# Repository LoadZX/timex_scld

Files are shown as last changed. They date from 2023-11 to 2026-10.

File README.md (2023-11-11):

# Timex SCLD

This is an implementation of the Timex TC2068 SCLD as can be found in Timex models TC2048 and TC2068.

# License

All the design files (VHDL code, PCB designs) are licensed under a Creative Commons Attribution-ShareAlike 4.0 International License.

You should have received a copy of the license along with this work. If not, see <https://creativecommons.org/licenses/by-sa/4.0/>.

A copy of the legal license text is placed in this repository (see LICENSE)

# Trademarks

TIMEX is a trademark of TIMEX GROUP USA, INC

The authors of this work are not affiliated, sponsored or have any partnership with the trademark holders. The trademark holders do not sponsor or endorse this work or any of its authors.

Xilinx is a registered trademark of Xilinx in the United States and other countries.

# Implementation code
The implementation (VHDL code and associated files) target a XC95144XL-10TQ100 CPLD from Xilinx. 

## Synthesis
The tool used for synthesis and fitting was Xilinx ISE 14.7. 

## Programming
Programming can be acomplished with Xilinx Impact using a proper programmer (i.e., Xilinx Platform Cable)

# Building

Just type "make" under the SDLC implementation folder (syn/xilinx). Alternatively you can try loading the ISE project in the same directory.

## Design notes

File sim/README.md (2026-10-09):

# TC2068 boot bench

Boots a minimal TC2068 around the SCLD in `../rtl` with the real HOME ROM and
EXROM, and writes the last video frame the SCLD produced as a PNG.

```sh
T80=/path/to/t80 MODELS=/path/to/models ROMS=/path/to/roms ./run.sh
```

| Variable | What it points at |
| --- | --- |
| `T80` | The T80 core: `T80_Pack`, `T80_ALU`, `T80_MCode`, `T80_Reg`, `T80`, `T80a` |
| `MODELS` | `hct245.vhd`, `mem_4416.vhd`, `mem_vram_16k.vhd`, `txt_util.vhd` |
| `ROMS` | `tc2068-0.rom` (HOME, 16K) and `tc2068-1.rom` (EXROM, 8K) |
| `RTL` | SCLD sources to test. Default `../rtl` |
| `MS` | Simulated milliseconds. Default 2000 |
| `HZ` | `50` or `60`: the SCLD's frame-rate strap, 312 or 262 lines. Default 50 |
| `OUT` | Work and output directory. Default `./work` |

None of the three inputs is in this repository. The ROMs are the ones Fuse
ships. GHDL and Python 3 are needed; nothing else.

The RAM test takes 1.7 s of simulated time, and the copyright screen is up by
2.0 s. A run of 2000 ms takes about six minutes.

## Reading the result

`work/frame.png` is the screen: exactly one frame, sync drawn black, so the
vertical sync is the black band along the bottom edge. `work/run.log` holds, in order:

- `IO  IN/OUT FF|F4 = ..` — every access to the two banking ports, with
  `READBACK MISMATCH` when a read does not return the last value written.
- `BUS FIGHT` — two outputs enabled at the instant the Z80 latched the bus.
- `T+nnn ms  PC=....  interrupts taken=n` — progress every 100 ms.

A good boot has no mismatch, no bus fight, and interrupts being taken from
about 1.8 s on.

`undefined byte read back` and `Z80 wrote an undefined byte` are about the CPU
model, not the SCLD: T80 leaves its registers uninitialised, and the ROM
pushes some of them before loading them.

## What is real and what is assumed

The SCLD, the Z80 bus timing (T80a), the 4416 DRAMs and the 74LS245 are
instantiated as they are. The board around them — address multiplexer, upper
RAM strobes, ROM enables — is a reconstruction and is not taken from a TC2068
netlist. The header of `tb_tc2068_boot.vhd` lists each assumption.

Nothing electrical is modelled. The bench cannot tell an NMOS Z80 from a CMOS
one, and it has no model of the boards that use series resistors in place of
the 74LS245.

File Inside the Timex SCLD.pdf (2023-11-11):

# Inside the Timex SCLD

A bit of history on the reverse engineering of the Timex SCLD integrated circuit

(C) 2023 Álvaro Lopes
Released under CC-BY-SA 4.0

## Table of Contents

Use case - Design a test case to understand when CPU contention

## Introduction

This document briefly documents the reasoning, rationale and effort done to successfully understand how the Timex SCLD (chip name “TS 2068 PAL”) works internally.
The intended audience is everyone who already has knowledge of the existence of the SCLD and basic notions of what the SCLD does in the Timex computers.
This document is based on a previous presentation I gave personally.
This document may include inaccuracies, simplifications and otherwise information that might not be entirely correct. Some of those are intentional and were chosen so to simplify the view for those who have less technical knowledge of the matters involved, some other are my own mistakes for which I apologise in advance.

## What is the SCLD

The SCLD is an integrated circuit present in some of the Timex compuer models, such as the portuguese TC2048 and TC2068.

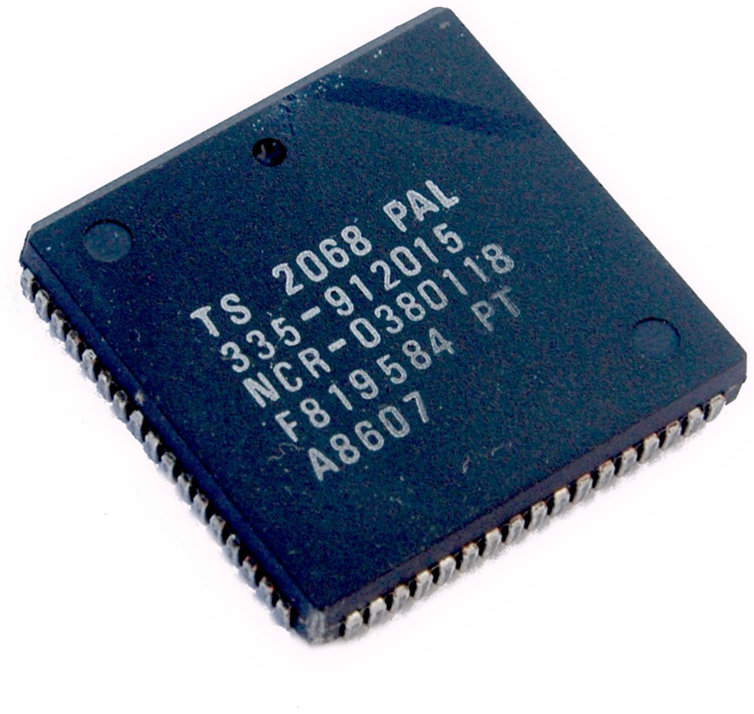
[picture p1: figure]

On the computer, the SCLD:
- Provides video signal (acts as the video card) and interface to the video memory
- Handles audio processing and keyboard
- Controls selection of ROMs and cartridges
- Generates CPU clock
- Generates “missing” signals for DRAM
- Adds IO ports to access AY-3-8910 external audio synthesizer IC.
- Handles both PAL and NTSC (via configuration pin and crystal selection -14MHz or 14.122MHz)
- Generates more video modes than ZX Spectrum ULA
- Although called TS2068, it is unrelated to the Timex model with same name.

## Why we did this - the Problem and the Solution

Well, to simplify, the problem was:
- The SCLD is no longer manufactured, and there are no internal design documents available.
- Replacing an SCLD on a Timex computer requires cannibalizing another Timex.
- It’s the only component missing for a successful implementation of a Timex clone.
So, what is the solution?
Well, the solution we decided upon can be summarized like this:
- Reverse engineer the SCLD from a functional perspective
- Use a COTS CPLD (Complex Programmable Logic Device) with eventual additional electronics to serve as a drop-in replacement
- Achievable with a printed circuit board with similar footprint
- A joint project with LOAD ZX Spectrum museum in Cantanhede, Portugal

## Reverse-engineering Integrated Circuits

There are several ways to reverse engineer ICs.
The most common are:
- Examination at transistor/wafer level
- Requires etching the IC die with chemicals, one layer at a time, to expose metal layers first and then the substrate.
- Requires complex imagery analysis.
- Some cells might be non-standard, increasing complexity.
- Examination at functional level
- Use a “testbench” to inject signals and observe outputs.
- Analyse data to understand behavior, and then infer the internal design.
We decided to perform the examination at the funcional level. For We had no access to equipment for transistor level examination, and we did not have the knowledge to perform that examination efficiently.

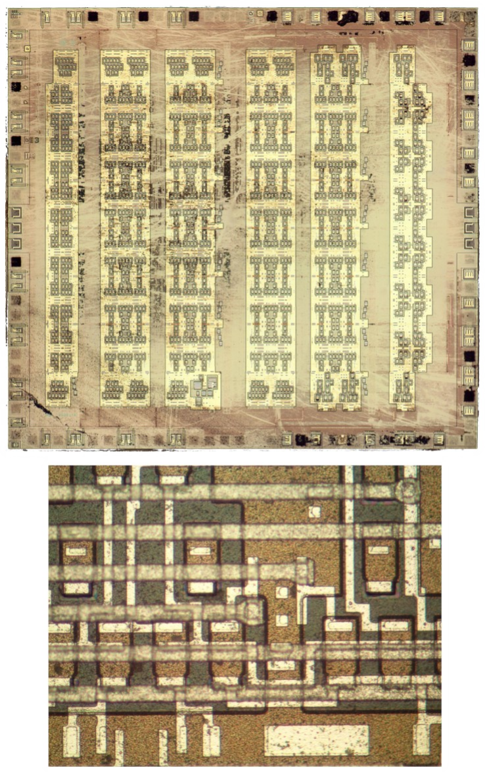
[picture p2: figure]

A ULA-Like exposed die after removing the metal layers and a close-up (with metal layers) of some transistors.
Photos © Ken Shirriff, https://www.righto.com/

## Functional reverse engineering

Two main types of funcional reverse engineering can be employed:
- Fully electronic
- Use signal generators (analogue and/or digital) to inject data on the device.
- Use digital analysers, data loggers and oscilloscopes to observe and record device outputs.
- Mixed software and hardware
- Microcontroller controls most inputs of the IC, and samples the IC outputs. Most suitable for digital devices, but analogue is also possible with some limitations.
- Minimal hardware required to interface the IC to a microcontroller.
For simplicity, we decided to use a mixed software and hardware approach. This meaning that we would design a basic hardware to interface to the SCLD, and then use a microcontroller (on our case, an ATMEGA2560) to perform the analysis, all connected to a standard PC linked via serial-over-USB.

## SCLD – where to start?

So, what do we know about the SCLD that allows us to start? Well,
- SCLD is based (roughly) on ZX Spectrum ULA, which has been reverse engineered.
- The SCLD functionality is documented to some extent (games use the functionality)
- Mostly synchronous device, based on logic gates and storage elements (flip-flops and latches)
- Typically runs off 14MHz external crystal (PAL systems) or 14.112MHz (NTSC systems)

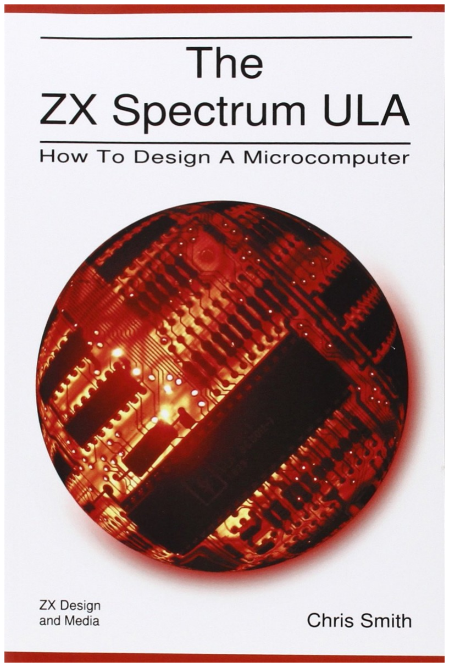
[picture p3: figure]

The ULA book from Chris Smith.

## The SCLD interface and the computer

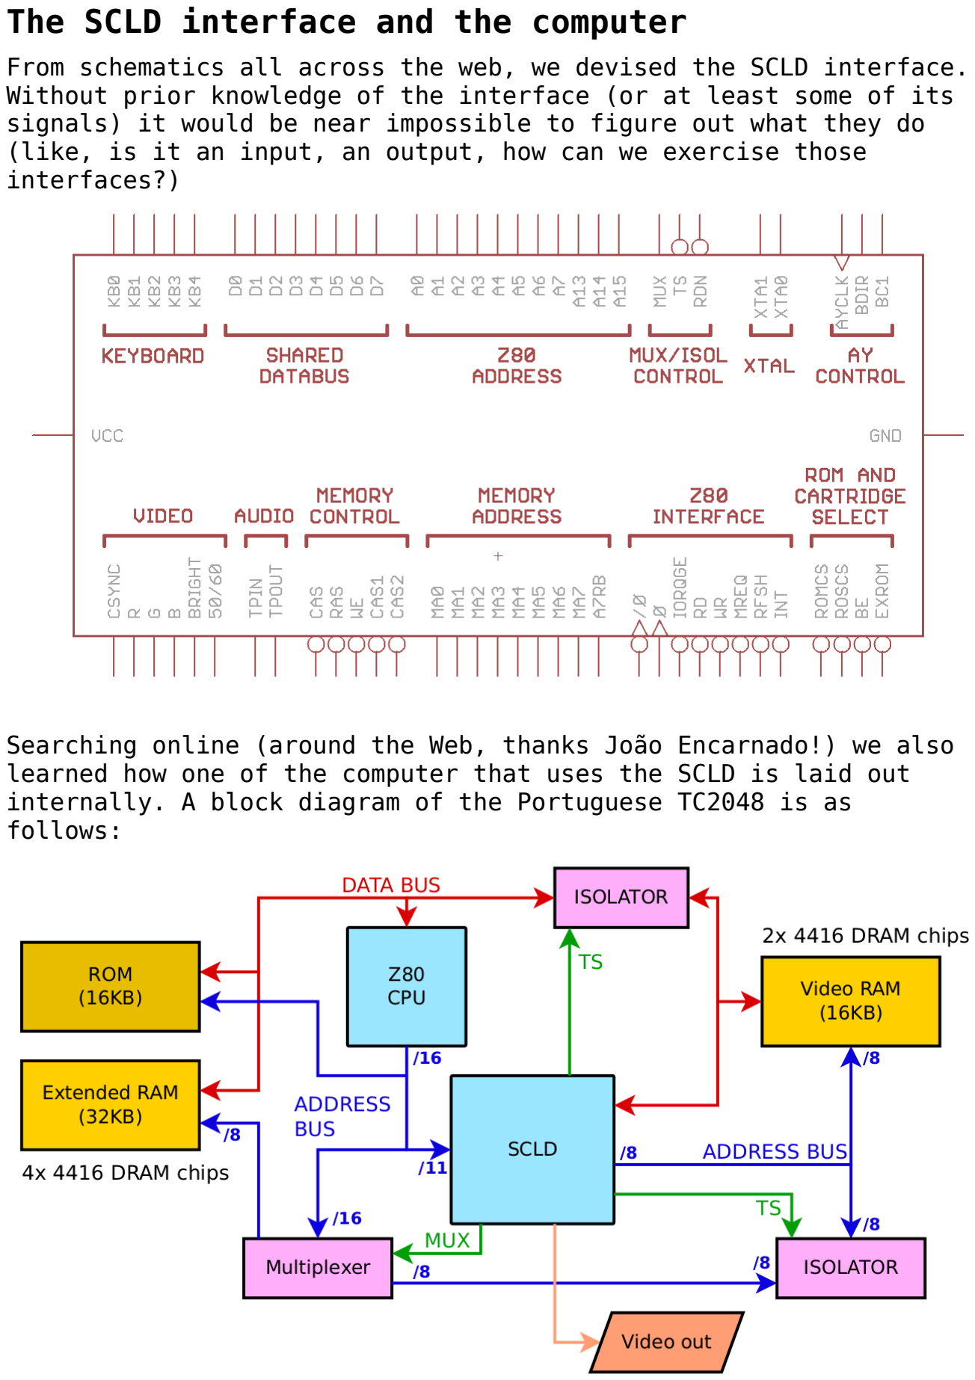
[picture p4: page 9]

From schematics all across the web, we devised the SCLD interface. Without prior knowledge of the interface (or at least some of its signals) it would be near impossible to figure out what they do (like, is it an input, an output, how can we exercise those interfaces?)

Searching online (around the Web, thanks João Encarnado!) we also learned how one of the computer that uses the SCLD is laid out internally. A block diagram of the Portuguese TC2048 is as follows:

## The approach

So, after analysing the SCLD interfaces and the TC2048 schematic, we decided on the following approach:
- Software-based test bench with custom board based on ATMEGA2560
- Run stimulus, capture output for analysis
- Design replacement using CPLD
- Run tests using the same framework targeting CPLD
- Board with SCLD socket – can target the SCLD itself or the CPLD (mutually exclusive)
- Header with all SCLD signals for oscilloscope inspection
- Cost-effective solution – less expensive than official Arduino Mega.

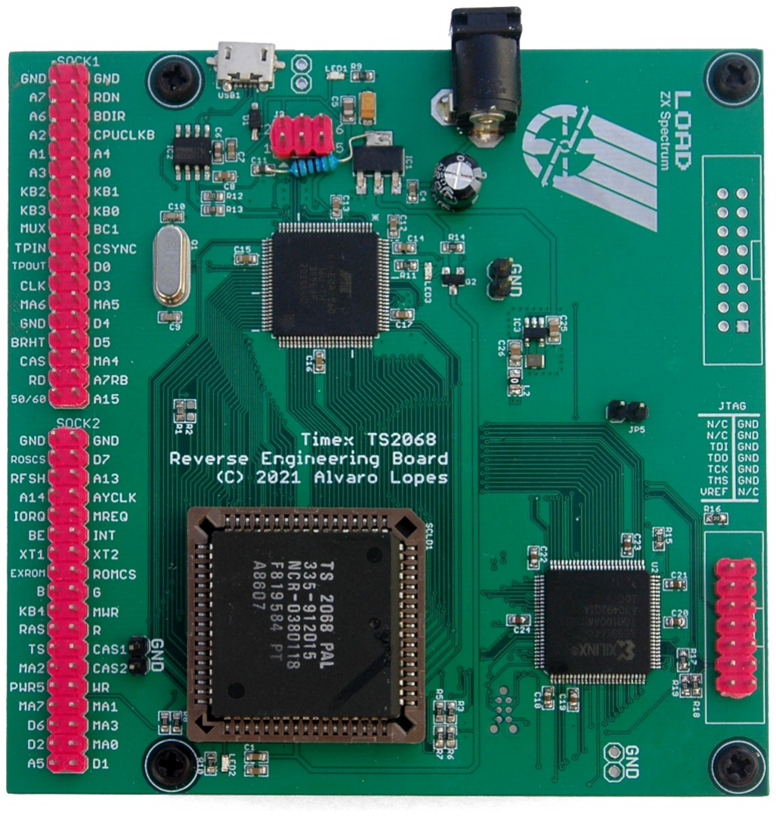
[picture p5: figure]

A picture of the “reverse engineering” board, with the SCLD attached on a PLCC socket. In addition to the ATMEGA2560, a CPLD intended to hold the redesigned CPLD has also been added (but never actually used).

## What can that system do?

The system, as simple as it might look, and with software even simpler than the hardware, can:
- Modulate SCLD clock (at a very low speed – not 14Mhz!)
- Simulate the Z80, RAM, keyboard and board discrete components (muxers, etc)
- Capture data from all digital SCLD pins .
- Pseudo event-triggered flow.
- Wait for signals to change – edge, level.
- Execute test cases in C++.
- Outputs industry standard VCD file (ASCII)

The software can be resumed like this:

- Simple approach, reads and writes individual SCLD signals.
- Has bus models to simulate nominal devices.
- Can emulate a Z80 CPU.
- Emulates RAM.
- Emulates Keyboard.
- No “video” generation at this point (for image inspection).
- Pseudo event-triggered flow
- Wait for signals to change – edge, level.
- Test cases can be linked in and executed after uploading to the board.
- The execution can be saved locally on a VCD file and can even be used to be “replayed” on a VHDL simulation on the replacement SCLD.

## Test cases

Well, not necessarly test cases - the system was designed to allow us to inject data and then we can observe the outputs on a waveform viewer, although it is possible to perform “checks” in run time while the test runs.
But before we start designing a new test case, we need to answer a few questions:
- What do you want to inspect or observe?
- What stimulus you need to provide to the SCLD
- How are those stimulus synchronized to the SCLD behavior
- How to implement the test case with the framework

## Use case - Design a test case to understand when CPU contention occurs

One of the hardest parts of understanding the behaviour of the SCLD is to understand how contention is implemented. Contention happens when both CPU and SCLD need to access the Lower RAM, and when this happens the CPU needs to be “stopped” and only resumed after the SCLD is finished.

Simultaneous access to different resources
When the CPU is accessing the extended RAM and the SCLD is accessing the Video (Lower) RAM, the isolators prevent mixing data and address [not all models have a physical isolator, sometimes only resistors].

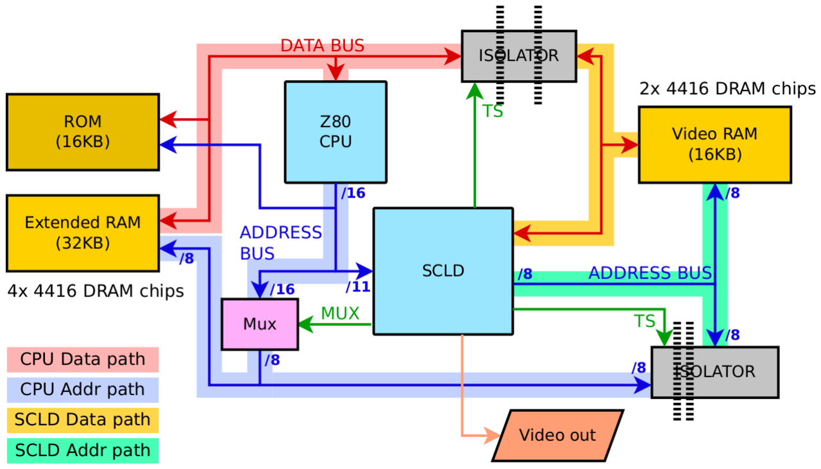
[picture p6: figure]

The isolation is controlled by the TS line.

Exclusive access to shared resource
When the CPU accessing the Video (Lower) RAM and the SCLD is not generating video, it floats the data and address bus to allow CPU access. The isolators move data between CPU and Video RAM.

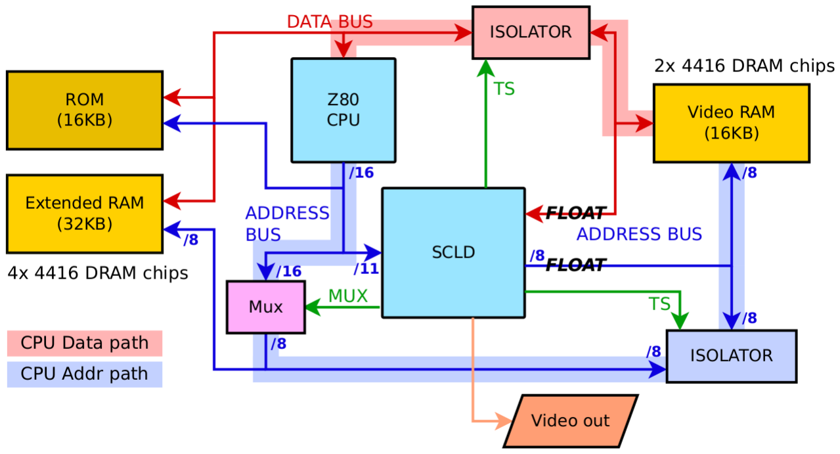
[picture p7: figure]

Simultaneous access to shared resource
When the CPU tries to access Video RAM and the SCLD is accessing Video RAM, the CPU needs to be “stopped” to prevent video being disturbed. This means that Isolators need to be active. Changes in video timing would cause artifacts to show on screen, such as horizontally displaced pixels and even invalid pixel data. CPU access can only resume/be processed after the video access from the SCLD.

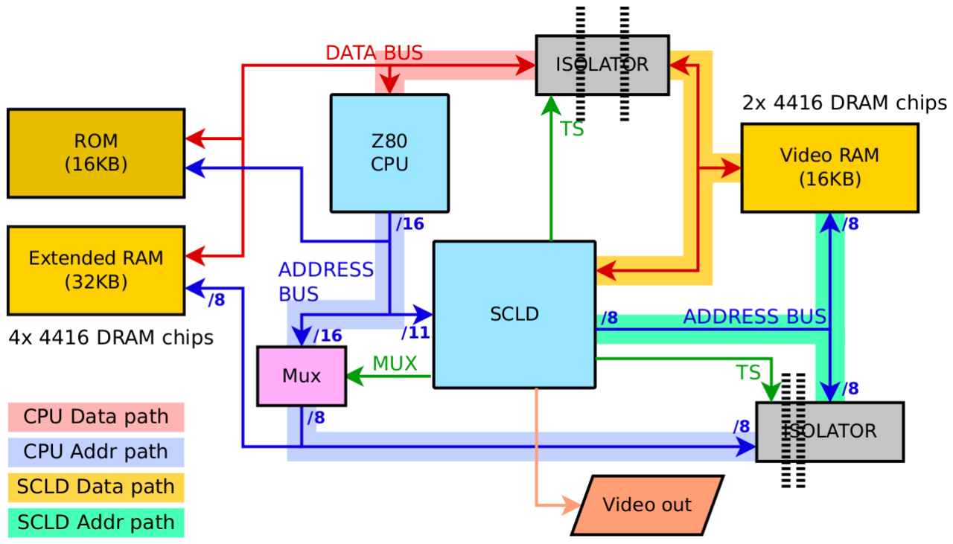
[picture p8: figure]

## Examining contention

We want to observe when contention occurs. Suspicion is that if access is performed near the actual instant the SCLD needs to access video memory, then the CPU is stopped.
For this, we need to trigger Z80 memory accesses at different times, and observe how the relative time between these accesses and the CPLD internal “workload” affects the contention.
We know (from the schematics) that TS line needs to be high for the SCLD to access the video RAM, so we schedule our reads in relation to the TS line.
Let’s delay from TS line going up a variable number of cycles and perform reads, then observe the output.

Implementing the test case
- Simple test with 30 iterations
- Clear address when no bus access is performed to be better visualised in VCD.
- Syncronise to TS line.
- Wait for a variable number of clock cycles.
- Perform a memory read to a fixed video RAM address (0x407A was arbitrarily chosen)

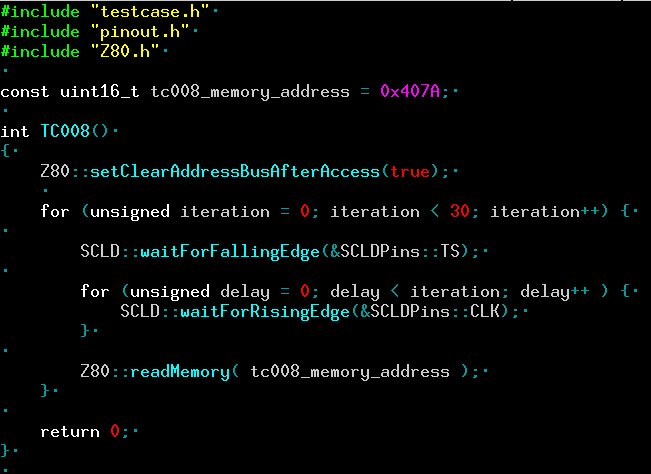
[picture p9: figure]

Initial run 1
- Wait TS for falling edge
- On iteration one, wait for one CLK (CPUCLK) rising edge
- Perform a typical Z80 Memory Read.

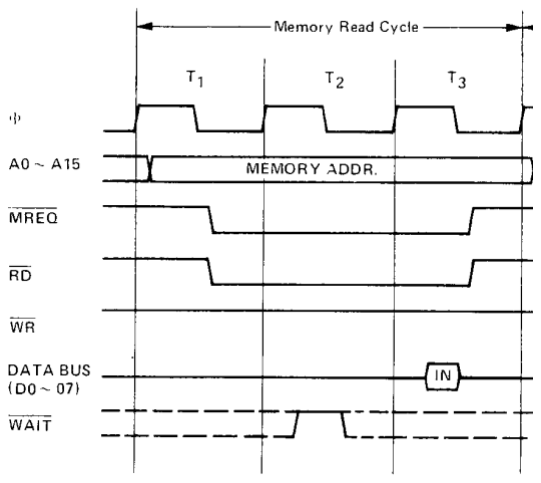
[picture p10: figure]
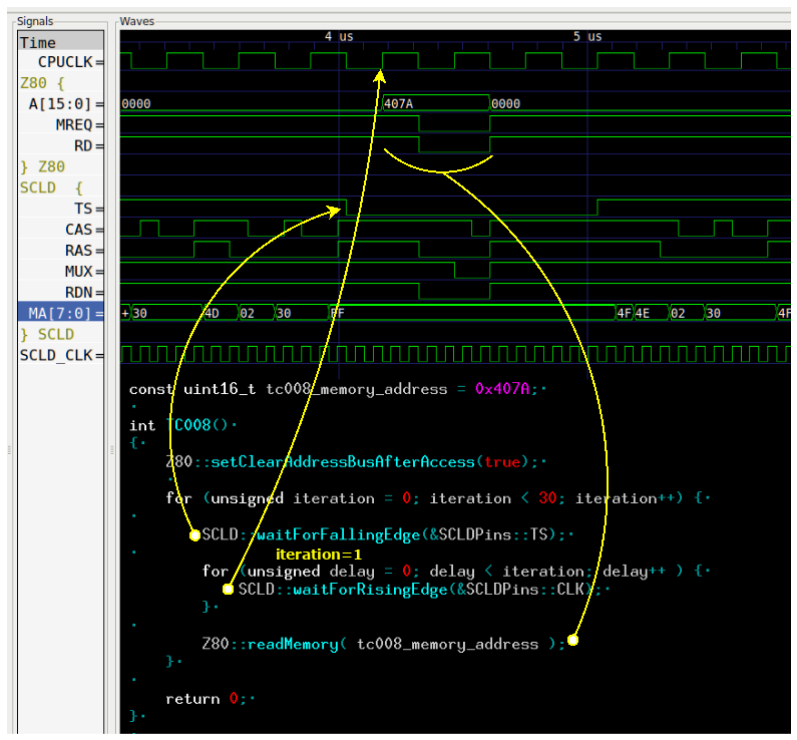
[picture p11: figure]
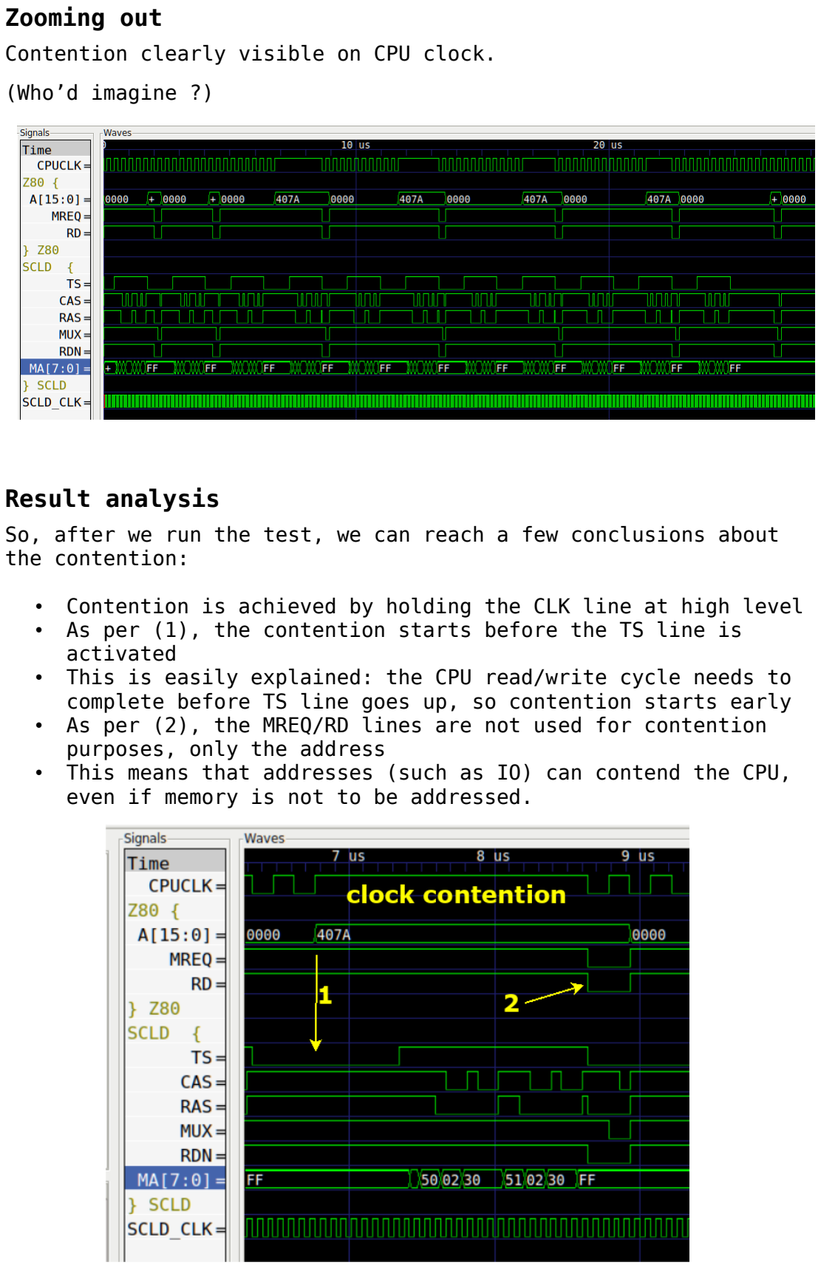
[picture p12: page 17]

Zooming out
Contention clearly visible on CPU clock. (Who’d imagine ?)

Result analysis
So, after we run the test, we can reach a few conclusions about the contention:
- Contention is achieved by holding the CLK line at high level
- As per (1), the contention starts before the TS line is activated
- This is easily explained: the CPU read/write cycle needs to complete before TS line goes up, so contention starts early
- As per (2), the MREQ/RD lines are not used for contention purposes, only the address
- This means that addresses (such as IO) can contend the CPU, even if memory is not to be addressed.

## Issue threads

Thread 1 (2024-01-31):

errata of the prototype schema

zambujal, 2024-01-31:
I don't understand.
 we must not use pin 23 so let him in high impedance
put the pin 64 with the signal for the cpu clock? we must programme the code for the xilinx?

zambujal, 2024-01-31:
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

zambujal, 2024-01-31:
I am still on the schema so I had put another buffer for the cpuclock . Will give the schema to you, I prefer Kicad so I migrated everything to kicad.

zambujal, 2024-02-02:
Ha... So I will wait. I made this with the older schematics...
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

zambujal, 2024-02-02:
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

zambujal, 2024-02-02:
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

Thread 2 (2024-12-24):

RGB output

Johnapteka, 2024-12-24:
Hi,
We should not use pull up resistors also at the output of the NC7WZ07?

alvieboy, 2024-12-25:
The component seems to be incorrect in the schematic. It should be NC7WZ17P6X. I'll update the schematics once I have some time, and then I will close this issue.

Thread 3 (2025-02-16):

Timex 2068 compatibility

Johnapteka, 2025-02-16:
Hi,
I try this version on a Timex 2068 and it fails.
It seems that trys to start the ROM, but at the last moment it gives some error.
The same computer with the original SCLD starts normally without errors.

Johnapteka, 2025-02-16:
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

Johnapteka, 2025-02-16:
<!-- Failed to upload "SCLD2068.mp4" -->

Johnapteka, 2025-02-16:
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

zambujal, 2025-03-30:
> Hi, I try this version on a Timex 2068 and it fails. It seems that trys to start the ROM, but at the last moment it gives some error. The same computer with the original SCLD starts normally without errors.

don't know if this will work... but there is some differences, and the rom is the biggest one the timex 2048 is effectively just closer to zx spectrum... I have the timmy from claudiuz, that is like somewhere between one and another... with the AY and all... I wonder.

1-did you tried to remove the tribuffer state for resistors?
2- my bet is something related with the rom but what....

will do this in a few weeks...

zambujal, 2025-03-30:
timmy has stuff from the timex 2068... :D Will test it in a few weeks.. have to make the pcb.. and if you already made one... can you share?

zambujal, 2025-03-30:
I opened a SCLD and took some pictures, this is another aproach for this... don't have a good microscope... but I might buy one ... and maybe use AI to decrypt what is inside this...

I opened it via antoine aproach... just need a good metalurgical microscope.

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

zambujal, 2025-03-30:
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

I wonder if our problems of compatibility is not due to BC1... my best guess...
without a good microscope, my bet is this... see the structures differences from output only pins... :D

zambujal, 2025-03-30:
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

zambujal, 2025-03-30:
There are some differences... Could be because of this.

Johnapteka, 2025-03-30:
I think the best approach would be to try to mimic how EXROM works. Comparing the signal from a SCLD in a real TC2068. Timmy is a good project but it is a clone of TC2048 with some extra features. I think it does not use the EXTROM signal that controls ROM2 on the TC2068. I've been looking at the EXROM signal code and it makes sense, it seems correct to me. I can't do a deeper analysis. I needed a good logic analyzer and try to understand what is happening at startup.

zambujal, 2025-03-31:
I just bought 3 analysers raspberry based 3 each 24 pins ... Timmy is not a 2068 ... Don't know if it's possible to change it to put ROM like cartridge and stuff ... If not I will use one of my Timex 2068 for this. Have to solder a socket like I did for Timmy.
________________________________
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

zambujal, 2025-03-31:
will do it... but
https://8bit-museum.de/scans/timex/tc2068schematic.jpg
the romCS I believe in this schematic have possibilities maybe because of differents roms?
exrom is only for the mask rom....rd and mreq must also be connected... I believe I can manipulate the timmy to get timex 2068 mode.... that way I feal less bad ... this are preciosities... and working with a real tc 2068 makes me feal bad.

________________________________
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

zambujal, 2025-05-07:
I am talking alone, but ok...
I got an bug mistake on the cpld code.
after the IA chatgpt started inventing ports for the exrom control...

por 246???

fala de out 246 ou seja porta 246 (decimal) onde viu isso?

Dito pelo ChatGPT:
Ótima pergunta — a referência ao OUT 246 (decimal) vem principalmente de duas fontes:

✅ 1. Análise reversa do SCLD no documento:
“Inside the Timex SCLD”, incluído no repositório GitHub LoadZX/timex_scld

Nesse documento (PDF), há uma seção detalhada que mostra que o SCLD no TS-2068 responde a:

OUT 255, X → controle global de banco

OUT 244, X → define banco no slot 1

OUT 246, X → define banco no slot 3, e ativa EXROM ou DOCK dependendo dos bits.

✅ 2. Código-fonte do VHDL real (timex_scld)
No arquivo memory_mapper.vhd, do projeto timex_scld, encontramos isso claramente:

vhdl
Copiar
Editar
-- OUT 0xF4 (244) = slot 1
-- OUT 0xF6 (246) = slot 3
...
if (io_addr = "11110110") then  -- 0xF6
    if wr = '0' and iorq = '0' then
        slot3_bank <= data_in(2 downto 0);
    end if;
end if;
Ou seja, OUT 246 (decimal) define qual banco vai no slot 3, que é onde o mapeamento de EXROM, DOCK e outros ocorre.

⏱ E mais: análise com analisador lógico
Você mencionou ter capturado isso com analisador — exatamente o que esperaríamos no arranque do TS‑2068:

plaintext
Copiar
Editar
OUT (255), 128   ; habilita controle de slots
OUT (244), 2     ; slot 1 = banco 2 (RAM)
OUT (246), 7     ; slot 3 = banco 7 → habilita EXROM
📌 Resumo
Porta	Função
OUT 255	Habilita/Desabilita controle de bancos
OUT 244	Escolhe banco para slot 1
OUT 246	Escolhe banco para slot 3 → ativa EXROM (slot3=7), DOCK, etc.

Posso te mostrar a lógica VHDL exata que gera o /EXROM se quiser ir para testes rápidos — quer isso?

Dito por si:
cuidado com o codigo do timex_scld... porta 246 acho que é sound... talvez um erro... bug... deveria ser 11110100 talvez e não 11110110

Dito pelo ChatGPT:
Excelente alerta — e você tem razão em duvidar!

Vamos esclarecer com base em evidência técnica e documentação original:

🧾 Porta 0xF6 (246): som (AY-3-8912)
De fato, no TS-2068, a porta 0xF6 é usada pelo chip de som AY-3-8912:

OUT 0xF6 = escreve dados no registrador selecionado do AY.

OUT 0xF4 = seleciona o número do registrador.

IN 0xF6 = lê do registrador.

📚 Isso está documentado no:

TS-2068 Technical Manual, seção 2.1.9 I/O Decoding

Esquema elétrico: Sinal WR + IORQ + endereço A7-A0 = 0xF4 e 0xF6 vão para o AY.

❌ Portanto, se o código VHDL está tratando 0xF6 como controle de banco de memória (slot 3)...
...isso é um bug ou má interpretação. A porta correta seria:

✅ 0xF4 (244): controle de banco (talvez slots 1 e 3 combinados)
No código-fonte do ZX Spectrum original e clones compatíveis (TC2048, TS2068, Pentagon), a lógica comum é:

Porta	Função esperada
0xFF (255)	Ativa o sistema de banco
0xF4 (244)	Controla qual banco vai em slot 1 (e possivelmente slot 3 em alguns mapeamentos)

📌 Diagnóstico
Você achou um ponto crítico:

O código VHDL do projeto timex_scld associa 0xF6 com mapeamento de slot 3, mas isso conflita com:

Uso legítimo dessa porta para som,

E também com o comportamento real observado na máquina (via analisador lógico, como você bem disse).

✅ Solução possível
O que provavelmente deveria acontecer:

OUT 0xFF → bit 7 ativa o sistema de banco

OUT 0xF4 → bits 0-2: banco para slot 1; bits 3-5: banco para slot 3

Ou então:

OUT 0xF4 controla slot 1

OUT 0xFD ou outra porta (não 0xF6) controla slot 3

Mas nunca 0xF6, se respeitarmos o mapeamento de som.

Posso ajudar de duas formas:
Reescrever a parte do memory_mapper.vhd removendo o uso indevido de 0xF6 e consolidando o mapeamento de EXROM/slot3 via 0xF4 (como parece ser o comportamento real).

Analisar as capturas do seu analisador lógico, se quiser compartilhar — assim vemos quais portas e dados realmente ocorrem no boot do TS-2068.

Você quer que eu corrija o trecho VHDL e te mostre como ficaria?

zambujal, 2025-05-08:
I put timmy on 2068 mode... :D removed a resistor and I had put the exrom via a wire... obviously I put a eprom 27c256 If my memory don't play me tricks...
when exrom activated... it is on the upper side of rom (where I had put the other rom of the 2068) I removed the romcs, just let it trough the memreq for the chip... removing the resistor that I mentioned and making an wire from the memreq ... to the right side of resistor. it just works.
I am also playing with out... and see the exrom behaviour... the problem lies on bank changing or with the activation of the exrom, I noticed it only on when acessing...

out 244,x and out 255,x lies our problems (my intuition says that) and yes exrom related for sure.

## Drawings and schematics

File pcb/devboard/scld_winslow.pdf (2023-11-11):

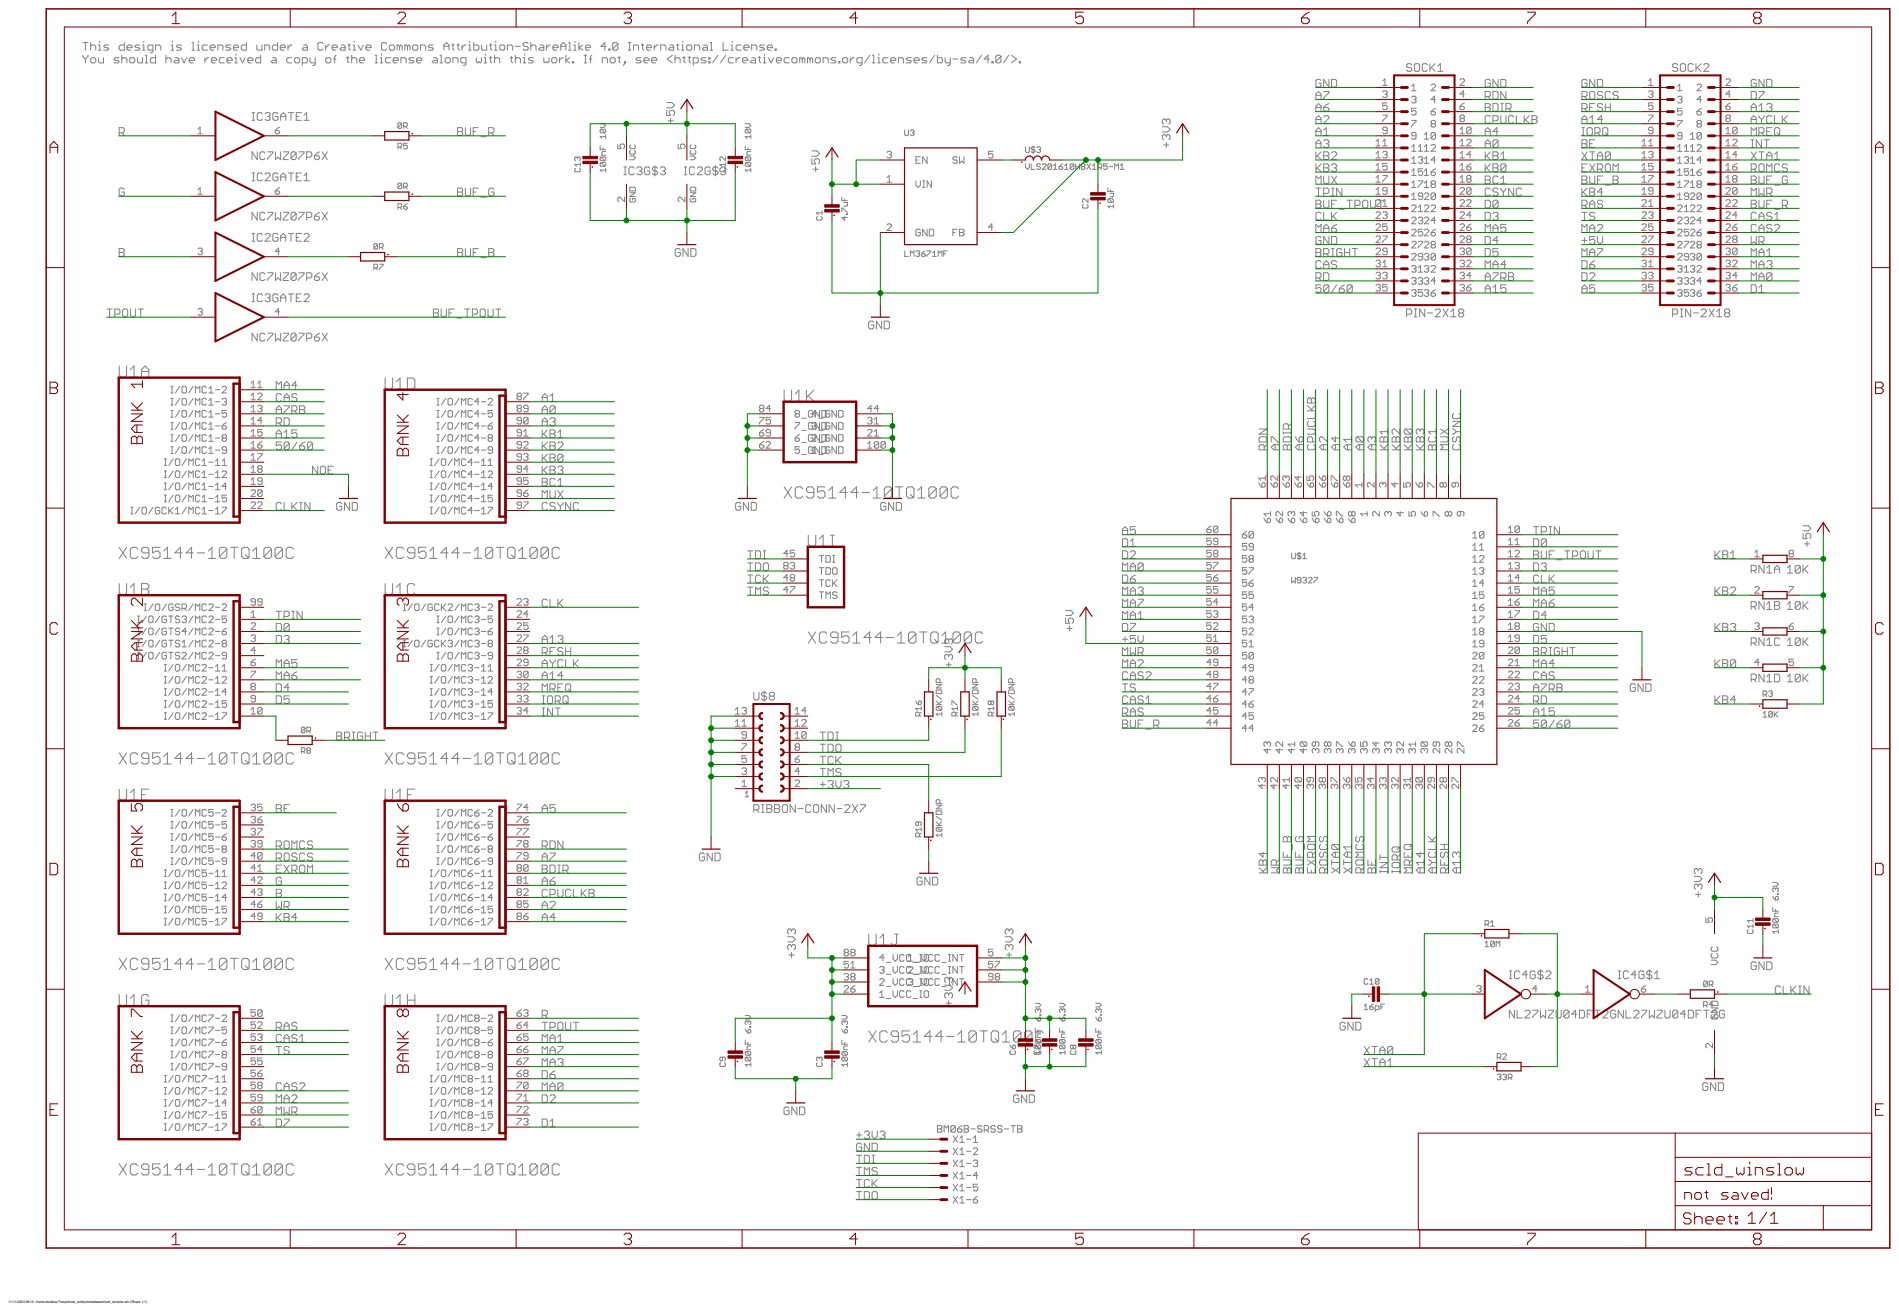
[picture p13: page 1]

11/11/2023 08:10 /home/alvieboy/Temp/timex_scld/pcb/testboard/scld_winslow.sch (Sheet: 1/1)

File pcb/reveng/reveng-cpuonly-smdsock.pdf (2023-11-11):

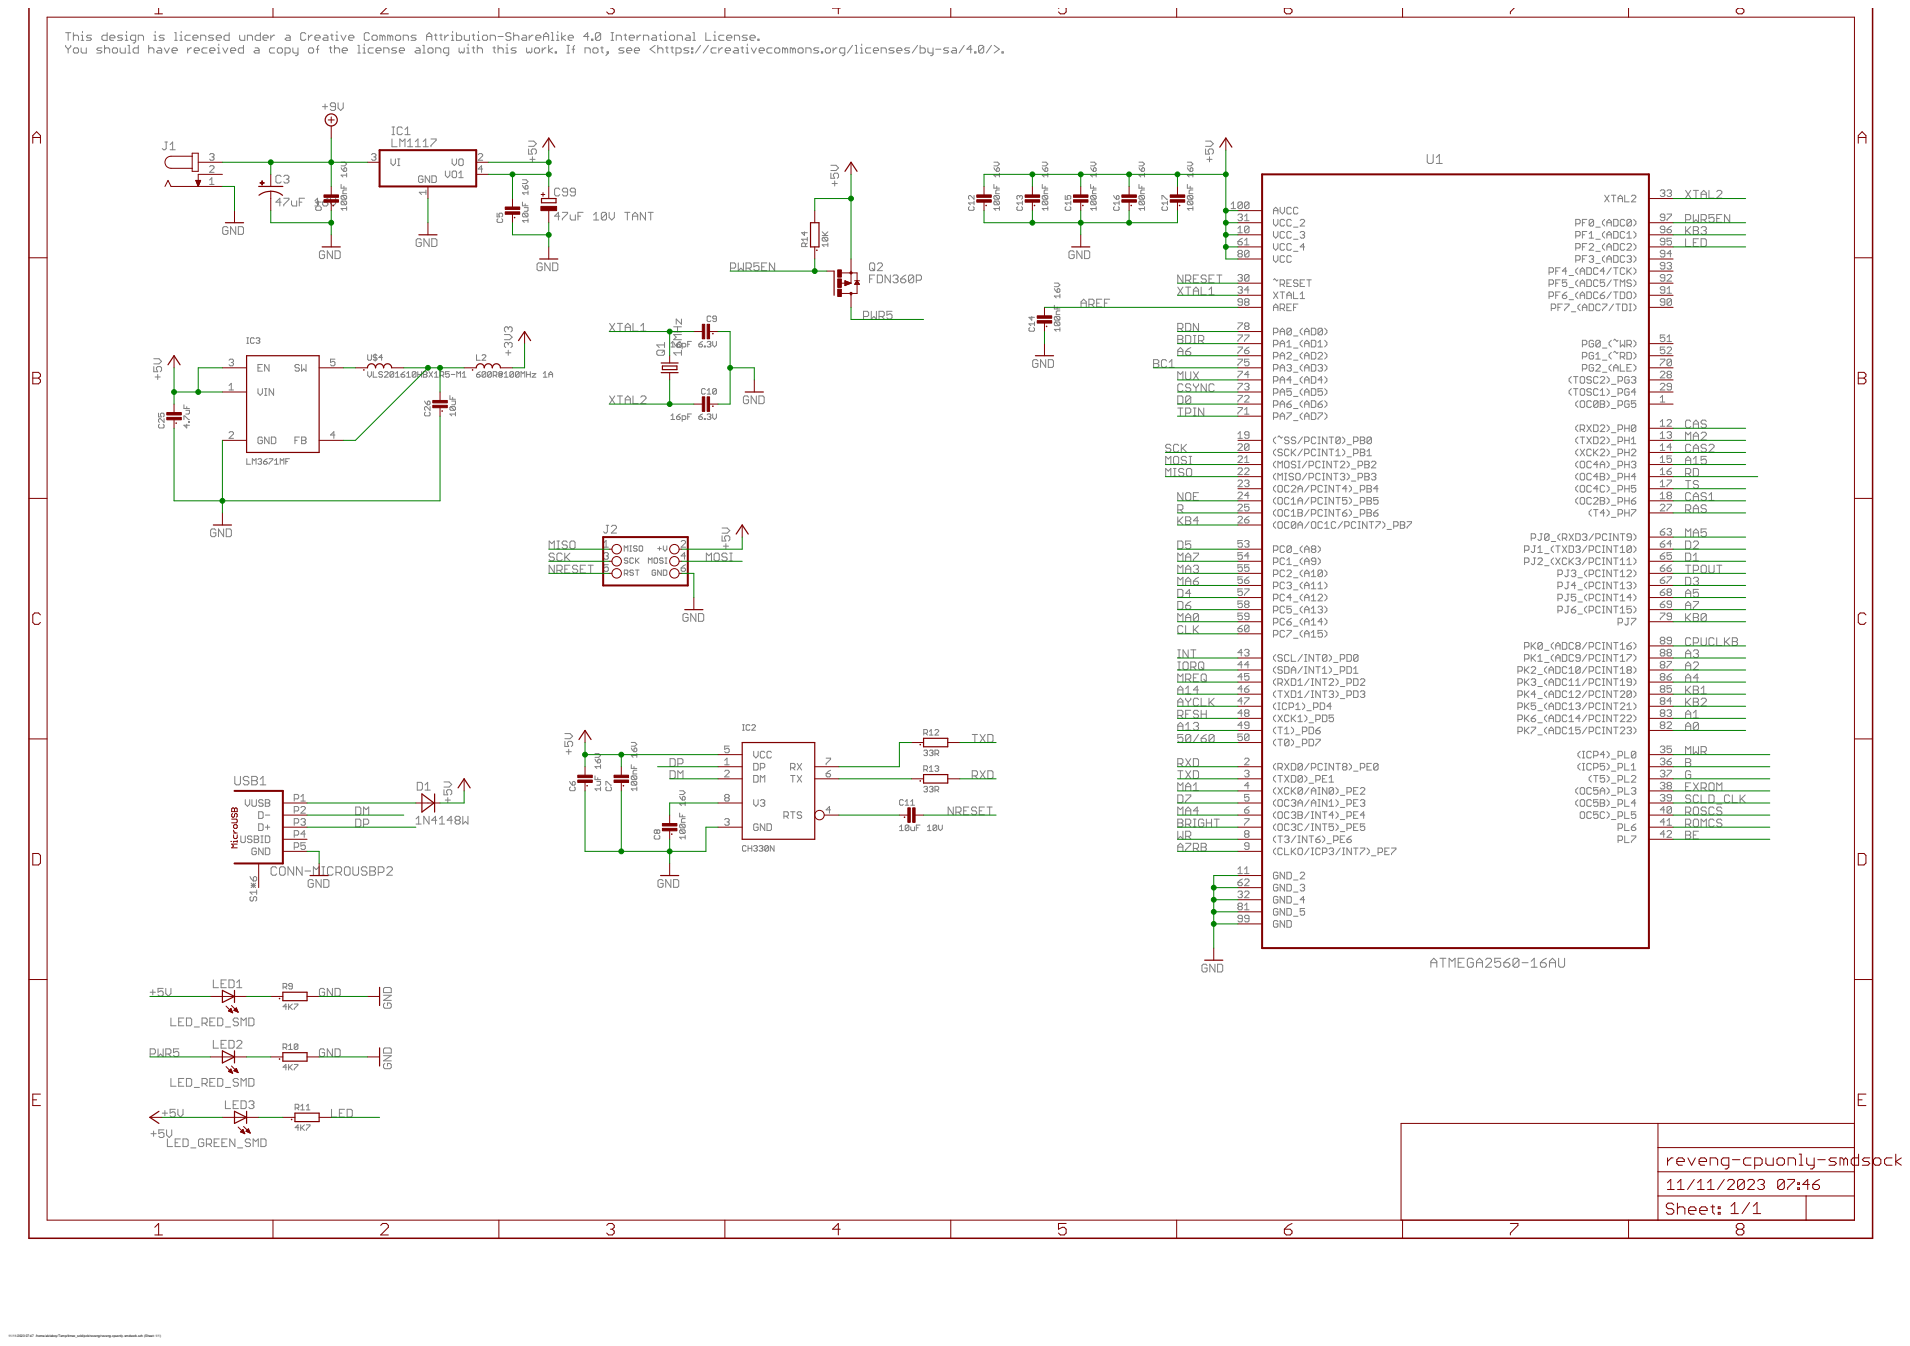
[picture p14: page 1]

11/11/2023 07:47 /home/alvieboy/Temp/timex_scld/pcb/reveng/reveng-cpuonly-smdsock.sch (Sheet: 1/1)

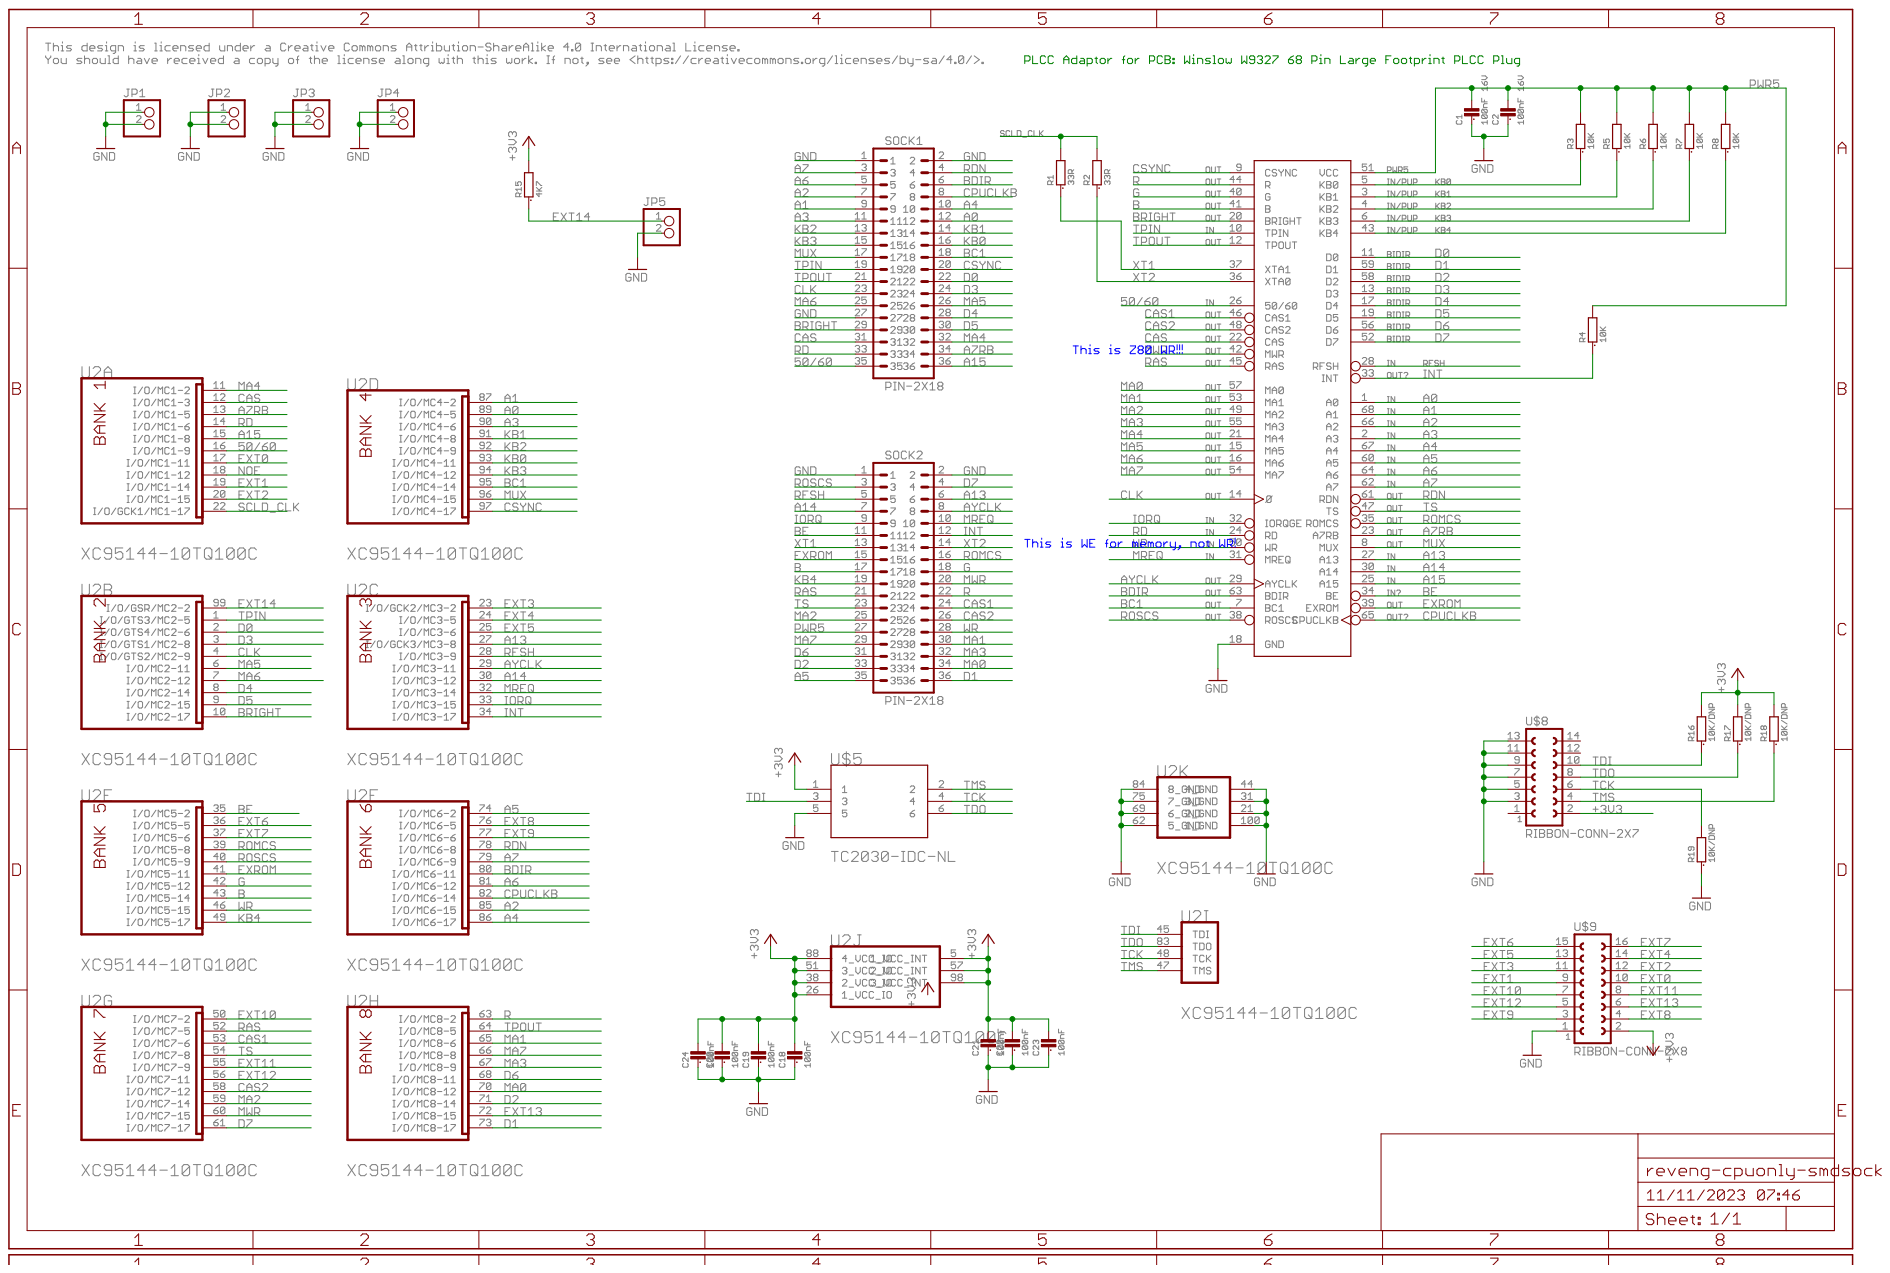
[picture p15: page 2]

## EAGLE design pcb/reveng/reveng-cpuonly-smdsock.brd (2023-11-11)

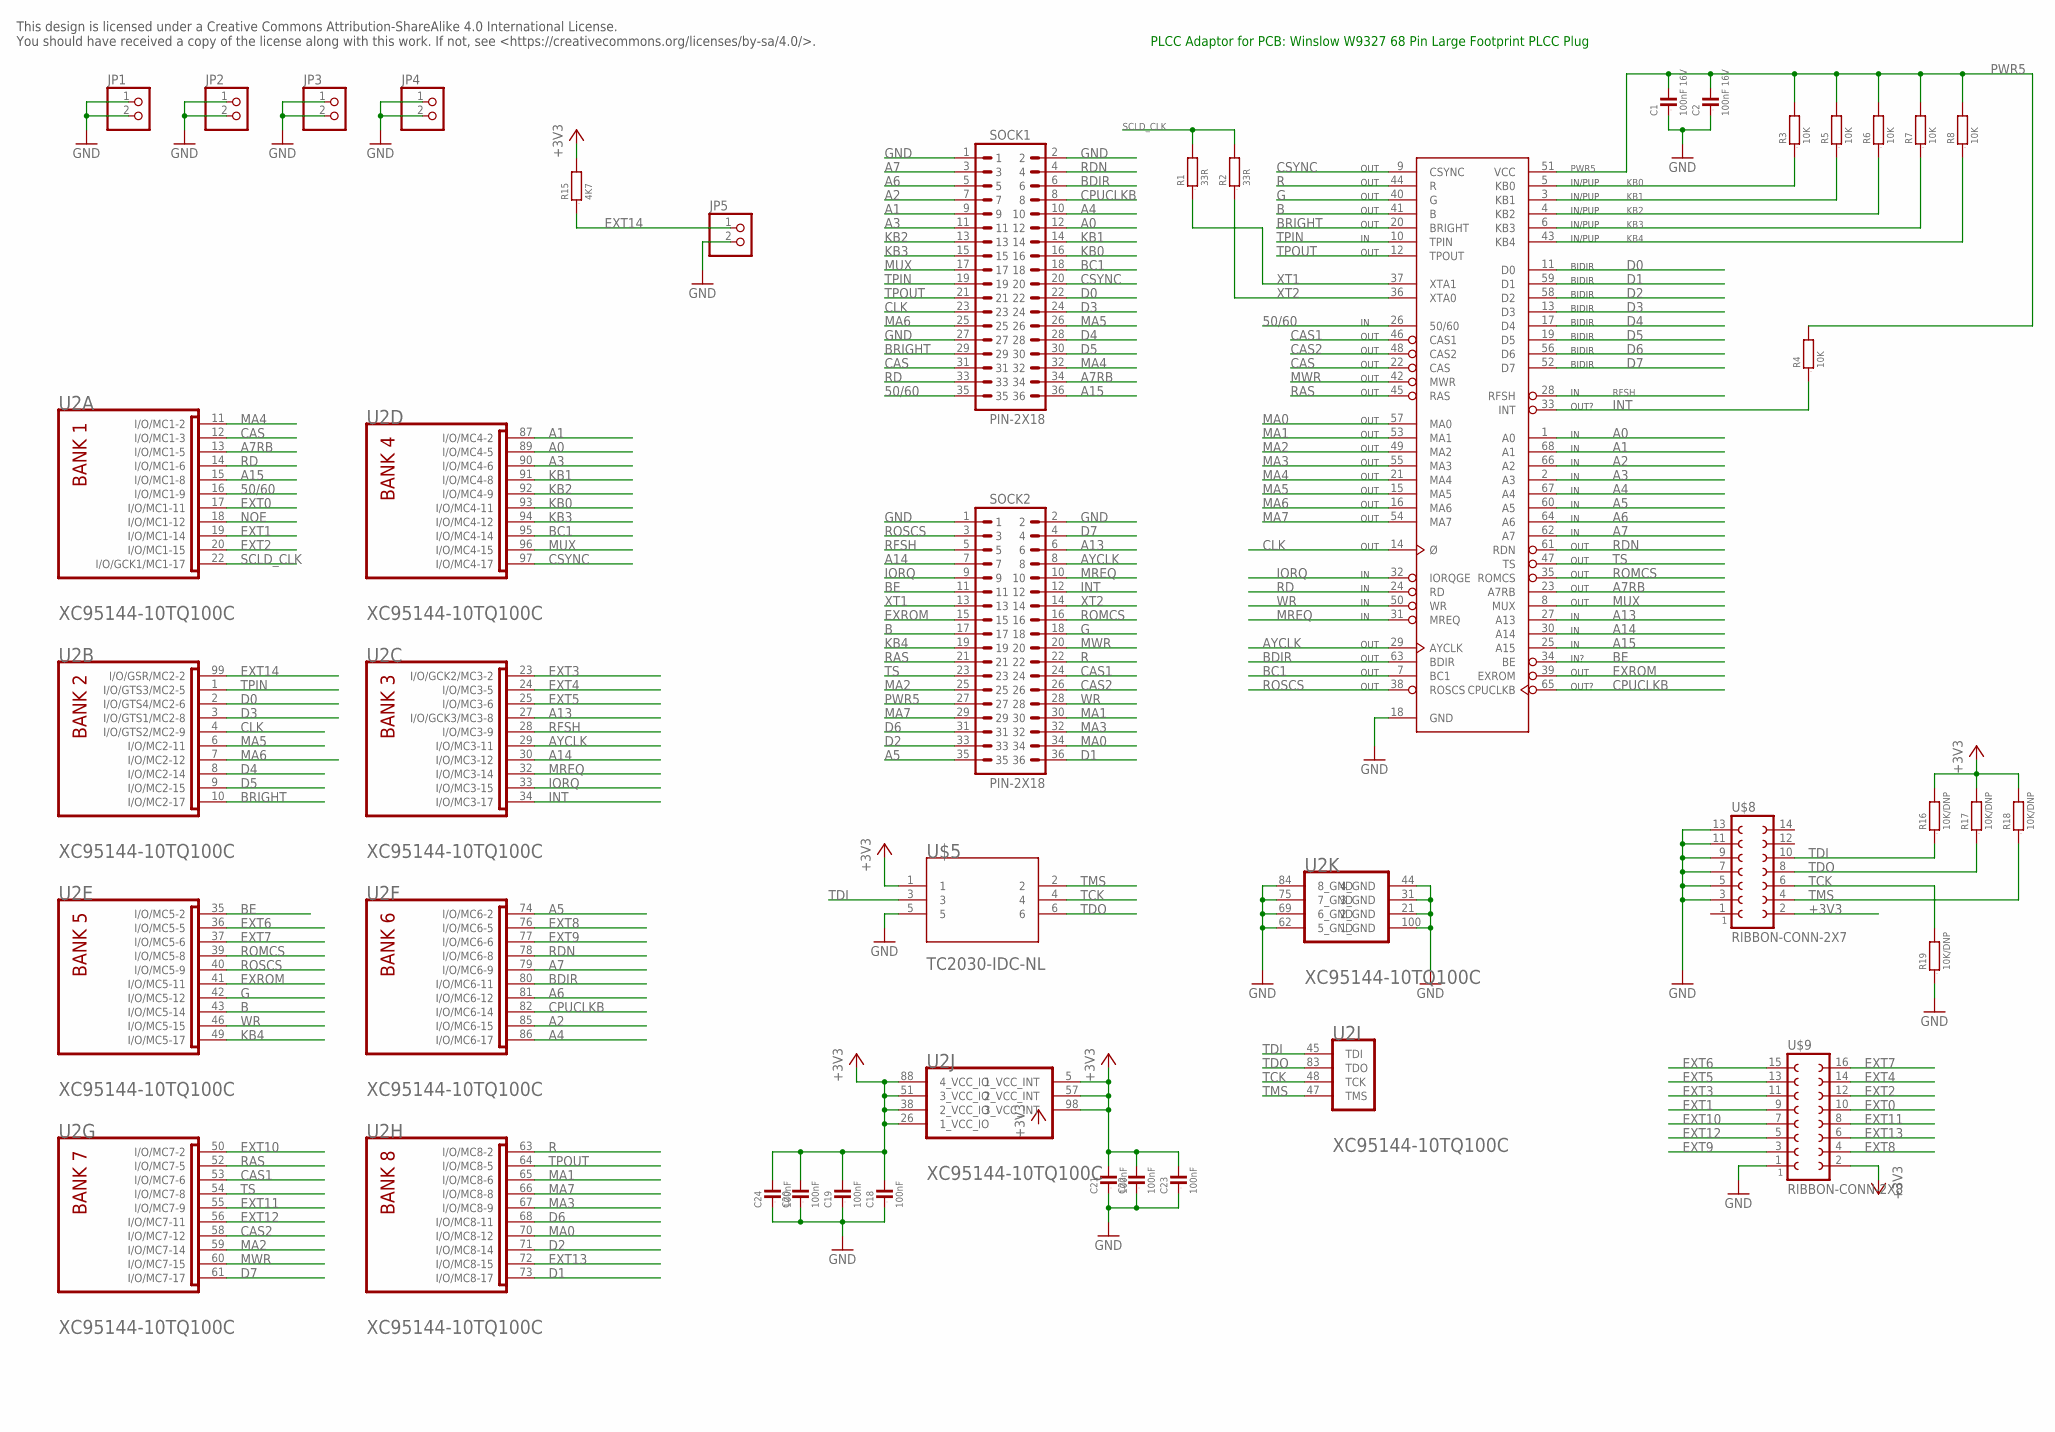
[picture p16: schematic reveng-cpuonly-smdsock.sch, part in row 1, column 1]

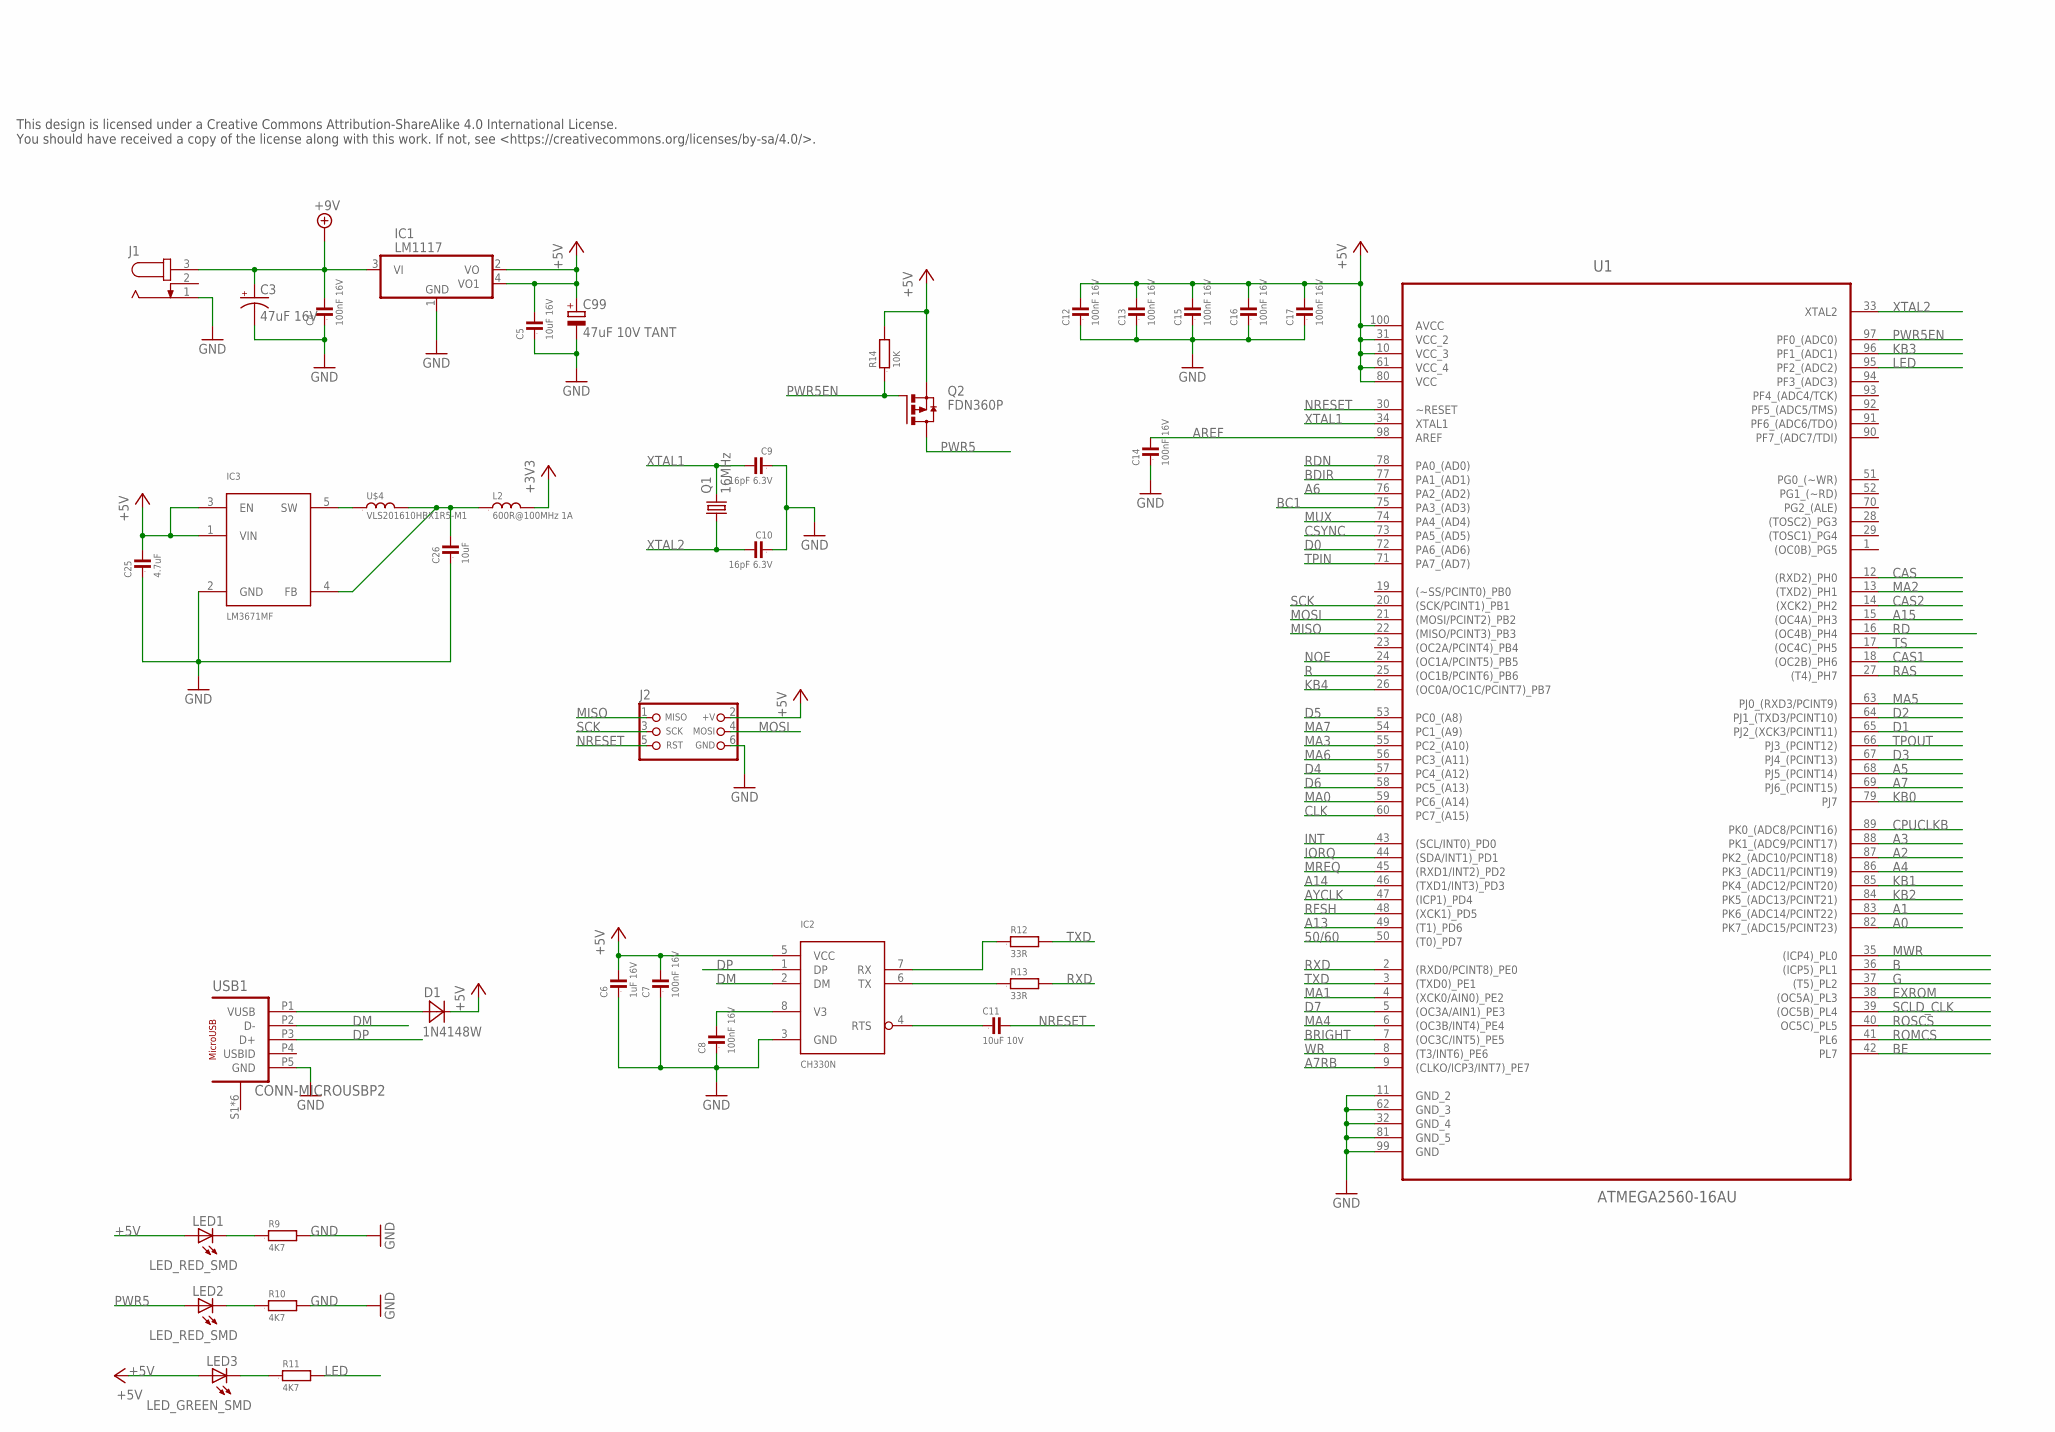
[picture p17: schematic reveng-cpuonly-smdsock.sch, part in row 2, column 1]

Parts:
C1, C2, C4, C7, C8, C12, C13, C14, C15, C16, C17: 100nF 16V; 0603
C3: 47uF 16V; E2,5-6
C5: 10uF 16V; 0805
C6: 1uF 16V; 0603
C9, C10: 16pF 6.3V; 0603
C11: 10uF 10V; 0603
C18, C19, C20, C21, C22, C23, C24: 100nF; 0603
C25: 4.7uF; 0805
C26: 10uF; 0805
C99: 47uF 10V TANT; TANT_CASE_A
D1: 1N4148W; SOD-123
IC1: LM1117; SOT223
IC2: CH330N; SOIC8
IC3: LM3671MF; SOT23-5L
J1: JACK-PLUG; SPC4078-NOSLOT
J2: CON_HEADER_PRG_AVR_ICSP-PTH; HEADER_PRG_2X03
JP1, JP2, JP3, JP4, JP5: PINHD-1X2; 1X02
L2: 600R@100MHz 1A; 0805
LED1, LED2: LED_RED_SMD; LED-603
LED3: LED_GREEN_SMD; LED-603
Q1: 16MHz; HC49U-V
Q2: FDN360P; SUPER-SOT3
R1, R2, R12, R13: 33R; 0603
R3, R4, R5, R6, R7, R8, R14: 10K; 0603
R9, R10, R11, R15: 4K7; 0603
R16, R17, R18, R19: 10K/DNP; 0603
SCLD1: 2048SCLDSMDSOCK; PLCC68-AMP-SOCKET
SOCK1, SOCK2: PIN-2X18
U1: ATMEGA2560-16AU; QFP50P1600X1600X120-100N
U2: XILINX_XC95144-10TQ100CLQFP; LQFP100
U$4: VLS201610HBX1R5-M1; IND_0806
U$5: TC2030-IDC-NL
U$8: RIBBON-CONN-2X7
U$9: RIBBON-CONN-2X8
USB1: CONN-MICROUSBP2; MICROUSB_SMD_TH_7.5MM_4.85MM

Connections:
50/60: SCLD1.26 (50/60), SOCK1.35, U1.50 ((T0)_PD7), U2.16 (I/O/MC1-9)
+3V3: C18.2, C19.2, C20.2, C21.2, C22.2, C23.2, C24.2, L2.2, R15.2, R16.2, R17.2, R18.2, U2.5 (1_VCC_INT), U2.26 (1_VCC_IO), U2.38 (2_VCC_IO), U2.51 (3_VCC_IO), U2.57 (2_VCC_INT), U2.88 (4_VCC_IO), U2.98 (3_VCC_INT), U$5.1, U$8.2, U$9.2
+5V: C5.2, C6.2, C7.2, C12.2, C13.2, C15.2, C16.2, C17.2, C25.2, C99.PLUS (+), D1.1 (C), IC1.2 (VO), IC1.4 (VO1), IC2.5 (VCC), IC3.1 (VIN), IC3.3 (EN), J2.2 (+V), LED1.A, LED3.A, Q2.2 (S), R14.2, U1.10 (VCC_3), U1.31 (VCC_2), U1.61 (VCC_4), U1.80 (VCC), U1.100 (AVCC)
+9V: C3.+, C4.2, IC1.3 (VI), J1.3
A0: SCLD1.1 (A0), SOCK1.12, U1.82 (PK7_(ADC15/PCINT23)), U2.89 (I/O/MC4-5)
A1: SCLD1.68 (A1), SOCK1.9, U1.83 (PK6_(ADC14/PCINT22)), U2.87 (I/O/MC4-2)
A2: SCLD1.66 (A2), SOCK1.7, U1.87 (PK2_(ADC10/PCINT18)), U2.85 (I/O/MC6-15)
A3: SCLD1.2 (A3), SOCK1.11, U1.88 (PK1_(ADC9/PCINT17)), U2.90 (I/O/MC4-6)
A4: SCLD1.67 (A4), SOCK1.10, U1.86 (PK3_(ADC11/PCINT19)), U2.86 (I/O/MC6-17)
A5: SCLD1.60 (A5), SOCK2.35, U1.68 (PJ5_(PCINT14)), U2.74 (I/O/MC6-2)
A6: SCLD1.64 (A6), SOCK1.5, U1.76 (PA2_(AD2)), U2.81 (I/O/MC6-12)
A7: SCLD1.62 (A7), SOCK1.3, U1.69 (PJ6_(PCINT15)), U2.79 (I/O/MC6-9)
A7RB: SCLD1.23 (A7RB), SOCK1.34, U1.9 ((CLKO/ICP3/INT7)_PE7), U2.13 (I/O/MC1-5)
A13: SCLD1.27 (A13), SOCK2.6, U1.49 ((T1)_PD6), U2.27 (I/O/GCK3/MC3-8)
A14: SCLD1.30 (A14), SOCK2.7, U1.46 ((TXD1/INT3)_PD3), U2.30 (I/O/MC3-12)
A15: SCLD1.25 (A15), SOCK1.36, U1.15 ((OC4A)_PH3), U2.15 (I/O/MC1-8)
AREF: C14.2, U1.98 (AREF)
AYCLK: SCLD1.29 (AYCLK), SOCK2.8, U1.47 ((ICP1)_PD4), U2.29 (I/O/MC3-11)
B: SCLD1.41 (B), SOCK2.17, U1.36 ((ICP5)_PL1), U2.43 (I/O/MC5-14)
BC1: SCLD1.7 (BC1), SOCK1.18, U1.75 (PA3_(AD3)), U2.95 (I/O/MC4-14)
BDIR: SCLD1.63 (BDIR), SOCK1.6, U1.77 (PA1_(AD1)), U2.80 (I/O/MC6-11)
BE: SCLD1.34 (BE), SOCK2.11, U1.42 (PL7), U2.35 (I/O/MC5-2)
BRIGHT: SCLD1.20 (BRIGHT), SOCK1.29, U1.7 ((OC3C/INT5)_PE5), U2.10 (I/O/MC2-17)
CAS: SCLD1.22 (CAS), SOCK1.31, U1.12 ((RXD2)_PH0), U2.12 (I/O/MC1-3)
CAS1: SCLD1.46 (CAS1), SOCK2.24, U1.18 ((OC2B)_PH6), U2.53 (I/O/MC7-6)
CAS2: SCLD1.48 (CAS2), SOCK2.26, U1.14 ((XCK2)_PH2), U2.58 (I/O/MC7-12)
CLK: SCLD1.14 (Ø), SOCK1.23, U1.60 (PC7_(A15)), U2.4 (I/O/GTS2/MC2-9)
CPUCLKB: SCLD1.65 (CPUCLKB), SOCK1.8, U1.89 (PK0_(ADC8/PCINT16)), U2.82 (I/O/MC6-14)
CSYNC: SCLD1.9 (CSYNC), SOCK1.20, U1.73 (PA5_(AD5)), U2.97 (I/O/MC4-17)
D0: SCLD1.11 (D0), SOCK1.22, U1.72 (PA6_(AD6)), U2.2 (I/O/GTS4/MC2-6)
D1: SCLD1.59 (D1), SOCK2.36, U1.65 (PJ2_(XCK3/PCINT11)), U2.73 (I/O/MC8-17)
D2: SCLD1.58 (D2), SOCK2.33, U1.64 (PJ1_(TXD3/PCINT10)), U2.71 (I/O/MC8-14)
D3: SCLD1.13 (D3), SOCK1.24, U1.67 (PJ4_(PCINT13)), U2.3 (I/O/GTS1/MC2-8)
D4: SCLD1.17 (D4), SOCK1.28, U1.57 (PC4_(A12)), U2.8 (I/O/MC2-14)
D5: SCLD1.19 (D5), SOCK1.30, U1.53 (PC0_(A8)), U2.9 (I/O/MC2-15)
D6: SCLD1.56 (D6), SOCK2.31, U1.58 (PC5_(A13)), U2.68 (I/O/MC8-11)
D7: SCLD1.52 (D7), SOCK2.4, U1.5 ((OC3A/AIN1)_PE3), U2.61 (I/O/MC7-17)
DM: IC2.2 (DM), USB1.P2 (D-)
DP: IC2.1 (DP), USB1.P3 (D+)
EXROM: SCLD1.39 (EXROM), SOCK2.15, U1.38 ((OC5A)_PL3), U2.41 (I/O/MC5-11)
EXT0: U2.17 (I/O/MC1-11), U$9.10
EXT1: U2.19 (I/O/MC1-14), U$9.9
EXT2: U2.20 (I/O/MC1-15), U$9.12
EXT3: U2.23 (I/O/GCK2/MC3-2), U$9.11
EXT4: U2.24 (I/O/MC3-5), U$9.14
EXT5: U2.25 (I/O/MC3-6), U$9.13
EXT6: U2.36 (I/O/MC5-5), U$9.15
EXT7: U2.37 (I/O/MC5-6), U$9.16
EXT8: U2.76 (I/O/MC6-5), U$9.4
EXT9: U2.77 (I/O/MC6-6), U$9.3
EXT10: U2.50 (I/O/MC7-2), U$9.7
EXT11: U2.55 (I/O/MC7-9), U$9.8
EXT12: U2.56 (I/O/MC7-11), U$9.5
EXT13: U2.72 (I/O/MC8-15), U$9.6
EXT14: JP5.1, R15.1, U2.99 (I/O/GSR/MC2-2)
G: SCLD1.40 (G), SOCK2.18, U1.37 ((T5)_PL2), U2.42 (I/O/MC5-12)
GND: C1.1, C2.1, C3.-, C4.1, C5.1, C6.1, C7.1, C8.1, C9.1, C10.1, C12.1, C13.1, C14.1, C15.1, C16.1, C17.1, C18.1, C19.1, C20.1, C21.1, C22.1, C23.1, C24.1, C25.1, C26.1, C99.MINUS (-), IC1.1 (GND), IC2.3 (GND), IC3.2 (GND), J1.1, J2.6 (GND), JP1.1, JP1.2, JP2.1, JP2.2, JP3.1, JP3.2, JP4.1, JP4.2, JP5.2, R9.2, R10.2, R19.1, SCLD1.18 (GND), SOCK1.1, SOCK1.2, SOCK1.27, SOCK2.1, SOCK2.2, U1.11 (GND_2), U1.32 (GND_4), U1.62 (GND_3), U1.81 (GND_5), U1.99 (GND), U2.21 (2_GND), U2.31 (3_GND), U2.44 (4_GND), U2.62 (5_GND), U2.69 (6_GND), U2.75 (7_GND), U2.84 (8_GND), U2.100 (1_GND), U$5.5, U$8.3, U$8.5, U$8.7, U$8.9, U$8.11, U$8.13, U$9.1, USB1.P5 (GND)
INT: R4.1, SCLD1.33 (INT), SOCK2.12, U1.43 ((SCL/INT0)_PD0), U2.34 (I/O/MC3-17)
IORQ: SCLD1.32 (IORQGE), SOCK2.9, U1.44 ((SDA/INT1)_PD1), U2.33 (I/O/MC3-15)
KB0: R3.1, SCLD1.5 (KB0), SOCK1.16, U1.79 (PJ7), U2.93 (I/O/MC4-11)
KB1: R5.1, SCLD1.3 (KB1), SOCK1.14, U1.85 (PK4_(ADC12/PCINT20)), U2.91 (I/O/MC4-8)
KB2: R6.1, SCLD1.4 (KB2), SOCK1.13, U1.84 (PK5_(ADC13/PCINT21)), U2.92 (I/O/MC4-9)
KB3: R7.1, SCLD1.6 (KB3), SOCK1.15, U1.96 (PF1_(ADC1)), U2.94 (I/O/MC4-12)
KB4: R8.1, SCLD1.43 (KB4), SOCK2.19, U1.26 ((OC0A/OC1C/PCINT7)_PB7), U2.49 (I/O/MC5-17)
LED: R11.2, U1.95 (PF2_(ADC2))
MA0: SCLD1.57 (MA0), SOCK2.34, U1.59 (PC6_(A14)), U2.70 (I/O/MC8-12)
MA1: SCLD1.53 (MA1), SOCK2.30, U1.4 ((XCK0/AIN0)_PE2), U2.65 (I/O/MC8-6)
MA2: SCLD1.49 (MA2), SOCK2.25, U1.13 ((TXD2)_PH1), U2.59 (I/O/MC7-14)
MA3: SCLD1.55 (MA3), SOCK2.32, U1.55 (PC2_(A10)), U2.67 (I/O/MC8-9)
MA4: SCLD1.21 (MA4), SOCK1.32, U1.6 ((OC3B/INT4)_PE4), U2.11 (I/O/MC1-2)
MA5: SCLD1.15 (MA5), SOCK1.26, U1.63 (PJ0_(RXD3/PCINT9)), U2.6 (I/O/MC2-11)
MA6: SCLD1.16 (MA6), SOCK1.25, U1.56 (PC3_(A11)), U2.7 (I/O/MC2-12)
MA7: SCLD1.54 (MA7), SOCK2.29, U1.54 (PC1_(A9)), U2.66 (I/O/MC8-8)
MISO: J2.1 (MISO), U1.22 ((MISO/PCINT3)_PB3)
MOSI: J2.4 (MOSI), U1.21 ((MOSI/PCINT2)_PB2)
MREQ: SCLD1.31 (MREQ), SOCK2.10, U1.45 ((RXD1/INT2)_PD2), U2.32 (I/O/MC3-14)
MUX: SCLD1.8 (MUX), SOCK1.17, U1.74 (PA4_(AD4)), U2.96 (I/O/MC4-15)
MWR: SCLD1.42 (MWR), SOCK2.20, U1.35 ((ICP4)_PL0), U2.60 (I/O/MC7-15)
unnamed: C8.2, IC2.8 (V3)
unnamed: D1.2 (A), USB1.P1 (VUSB)
unnamed: IC2.7 (RX), R12.1
unnamed: IC2.6 (TX), R13.1
unnamed: C11.1, IC2.4 (RTS)
unnamed: LED2.C, R10.1
unnamed: LED3.C, R11.1
unnamed: LED1.C, R9.1
NOE: U1.24 ((OC1A/PCINT5)_PB5), U2.18 (I/O/MC1-12)
NRESET: C11.2, J2.5 (RST), U1.30 (~RESET)
PWR5: C1.2, C2.2, LED2.A, Q2.3 (D), R3.2, R4.2, R5.2, R6.2, R7.2, R8.2, SCLD1.51 (VCC), SOCK2.27
PWR5EN: Q2.1 (G), R14.1, U1.97 (PF0_(ADC0))
R: SCLD1.44 (R), SOCK2.22, U1.25 ((OC1B/PCINT6)_PB6), U2.63 (I/O/MC8-2)
RAS: SCLD1.45 (RAS), SOCK2.21, U1.27 ((T4)_PH7), U2.52 (I/O/MC7-5)
RD: SCLD1.24 (RD), SOCK1.33, U1.16 ((OC4B)_PH4), U2.14 (I/O/MC1-6)
RDN: SCLD1.61 (RDN), SOCK1.4, U1.78 (PA0_(AD0)), U2.78 (I/O/MC6-8)
RFSH: SCLD1.28 (RFSH), SOCK2.5, U1.48 ((XCK1)_PD5), U2.28 (I/O/MC3-9)
ROMCS: SCLD1.35 (ROMCS), SOCK2.16, U1.41 (PL6), U2.39 (I/O/MC5-8)
ROSCS: SCLD1.38 (ROSCS), SOCK2.3, U1.40 (OC5C)_PL5), U2.40 (I/O/MC5-9)
RXD: R13.2, U1.2 ((RXD0/PCINT8)_PE0)
SCK: J2.3 (SCK), U1.20 ((SCK/PCINT1)_PB1)
SCLD_CLK: R1.2, R2.2, U1.39 ((OC5B)_PL4), U2.22 (I/O/GCK1/MC1-17)
SW: IC3.5 (SW), U$4.P$1 (1)
TCK: R19.2, U2.48 (TCK), U$5.4, U$8.6
TDI: R16.1, U2.45 (TDI), U$5.3, U$8.10
TDO: R17.1, U2.83 (TDO), U$5.6, U$8.8
TMS: R18.1, U2.47 (TMS), U$5.2, U$8.4
TPIN: SCLD1.10 (TPIN), SOCK1.19, U1.71 (PA7_(AD7)), U2.1 (I/O/GTS3/MC2-5)
TPOUT: SCLD1.12 (TPOUT), SOCK1.21, U1.66 (PJ3_(PCINT12)), U2.64 (I/O/MC8-5)
TS: SCLD1.47 (TS), SOCK2.23, U1.17 ((OC4C)_PH5), U2.54 (I/O/MC7-8)
TXD: R12.2, U1.3 ((TXD0)_PE1)
V33: C26.2, IC3.4 (FB), L2.1, U$4.P$2 (2)
WR: SCLD1.50 (WR), SOCK2.28, U1.8 ((T3/INT6)_PE6), U2.46 (I/O/MC5-15)
XT1: R1.1, SCLD1.37 (XTA1), SOCK2.13
XT2: R2.1, SCLD1.36 (XTA0), SOCK2.14
XTAL1: C9.2, Q1.2, U1.34 (XTAL1)
XTAL2: C10.2, Q1.1, U1.33 (XTAL2)

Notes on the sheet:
BIDIR
OUT
OUT?
IN/PUP
IN?
PLCC Adaptor for PCB: Winslow W9327 68 Pin Large Footprint PLCC Plug
This design is licensed under a Creative Commons Attribution-ShareAlike 4.0 International License. You should have received a copy of the license along with this work. If not, see <https://creativecommons.org/licenses/by-sa/4.0/>.

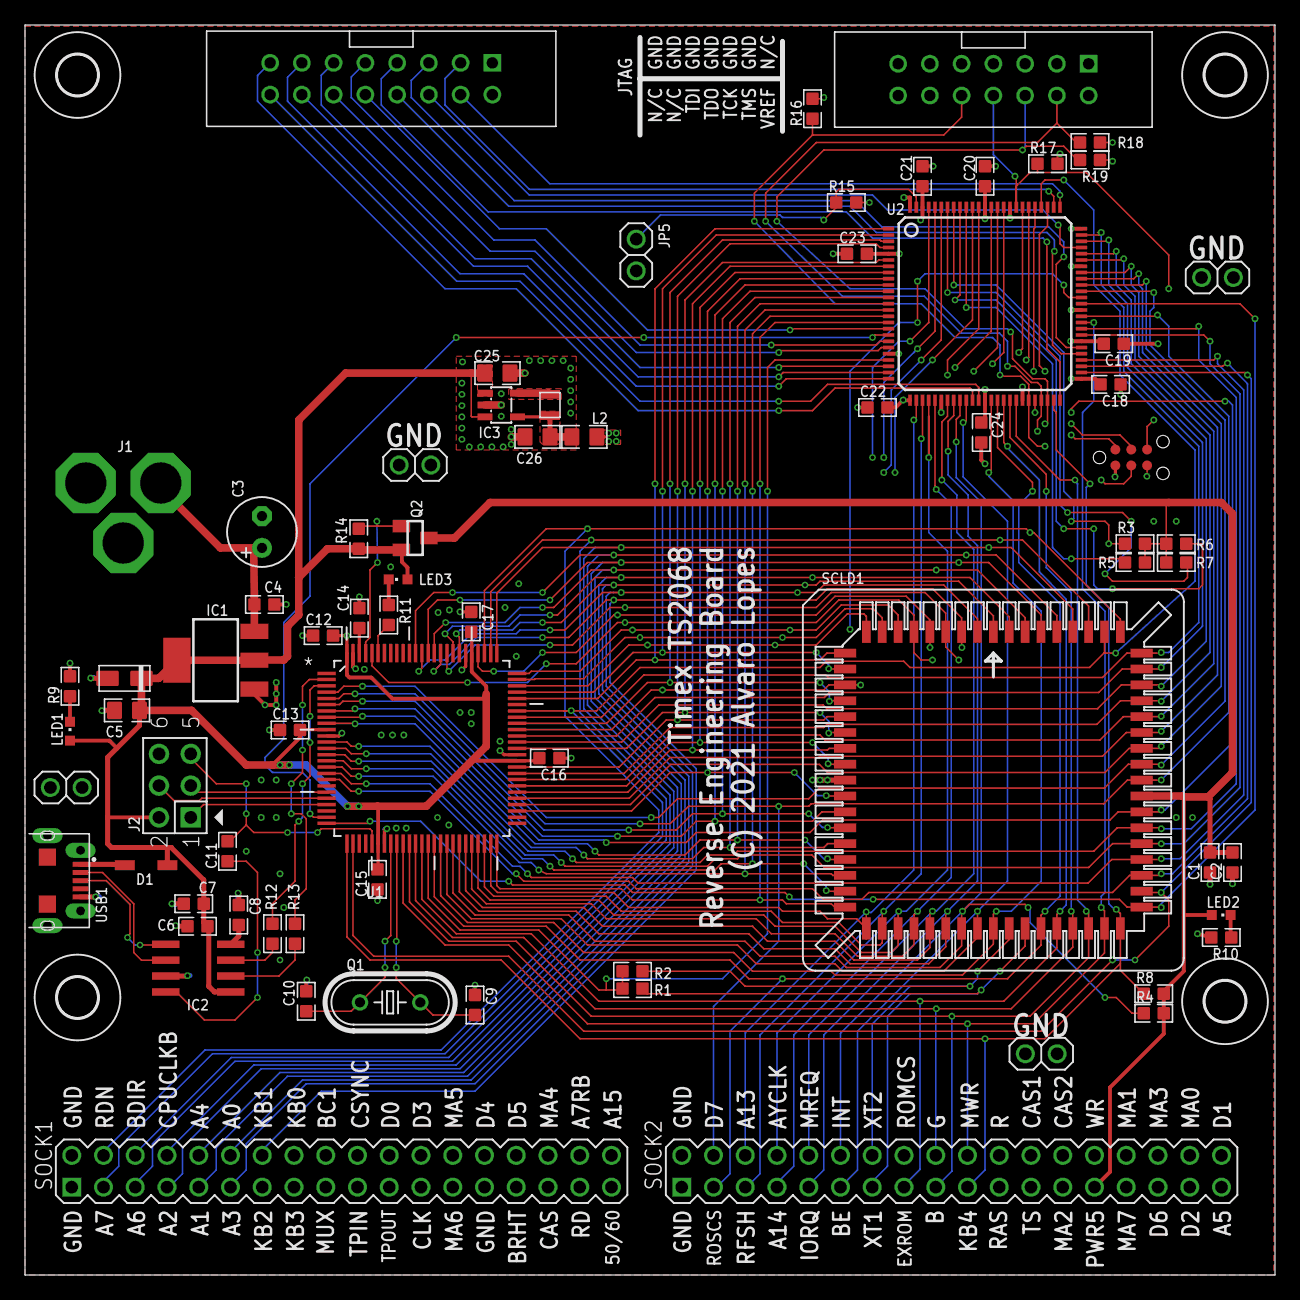
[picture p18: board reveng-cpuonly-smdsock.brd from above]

Board: 4 copper layers, 100.0 x 100.0 mm, 77 parts (0 on the bottom side), 115 nets.

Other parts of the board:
U$6, U$7, U$10, U$11: 3,2

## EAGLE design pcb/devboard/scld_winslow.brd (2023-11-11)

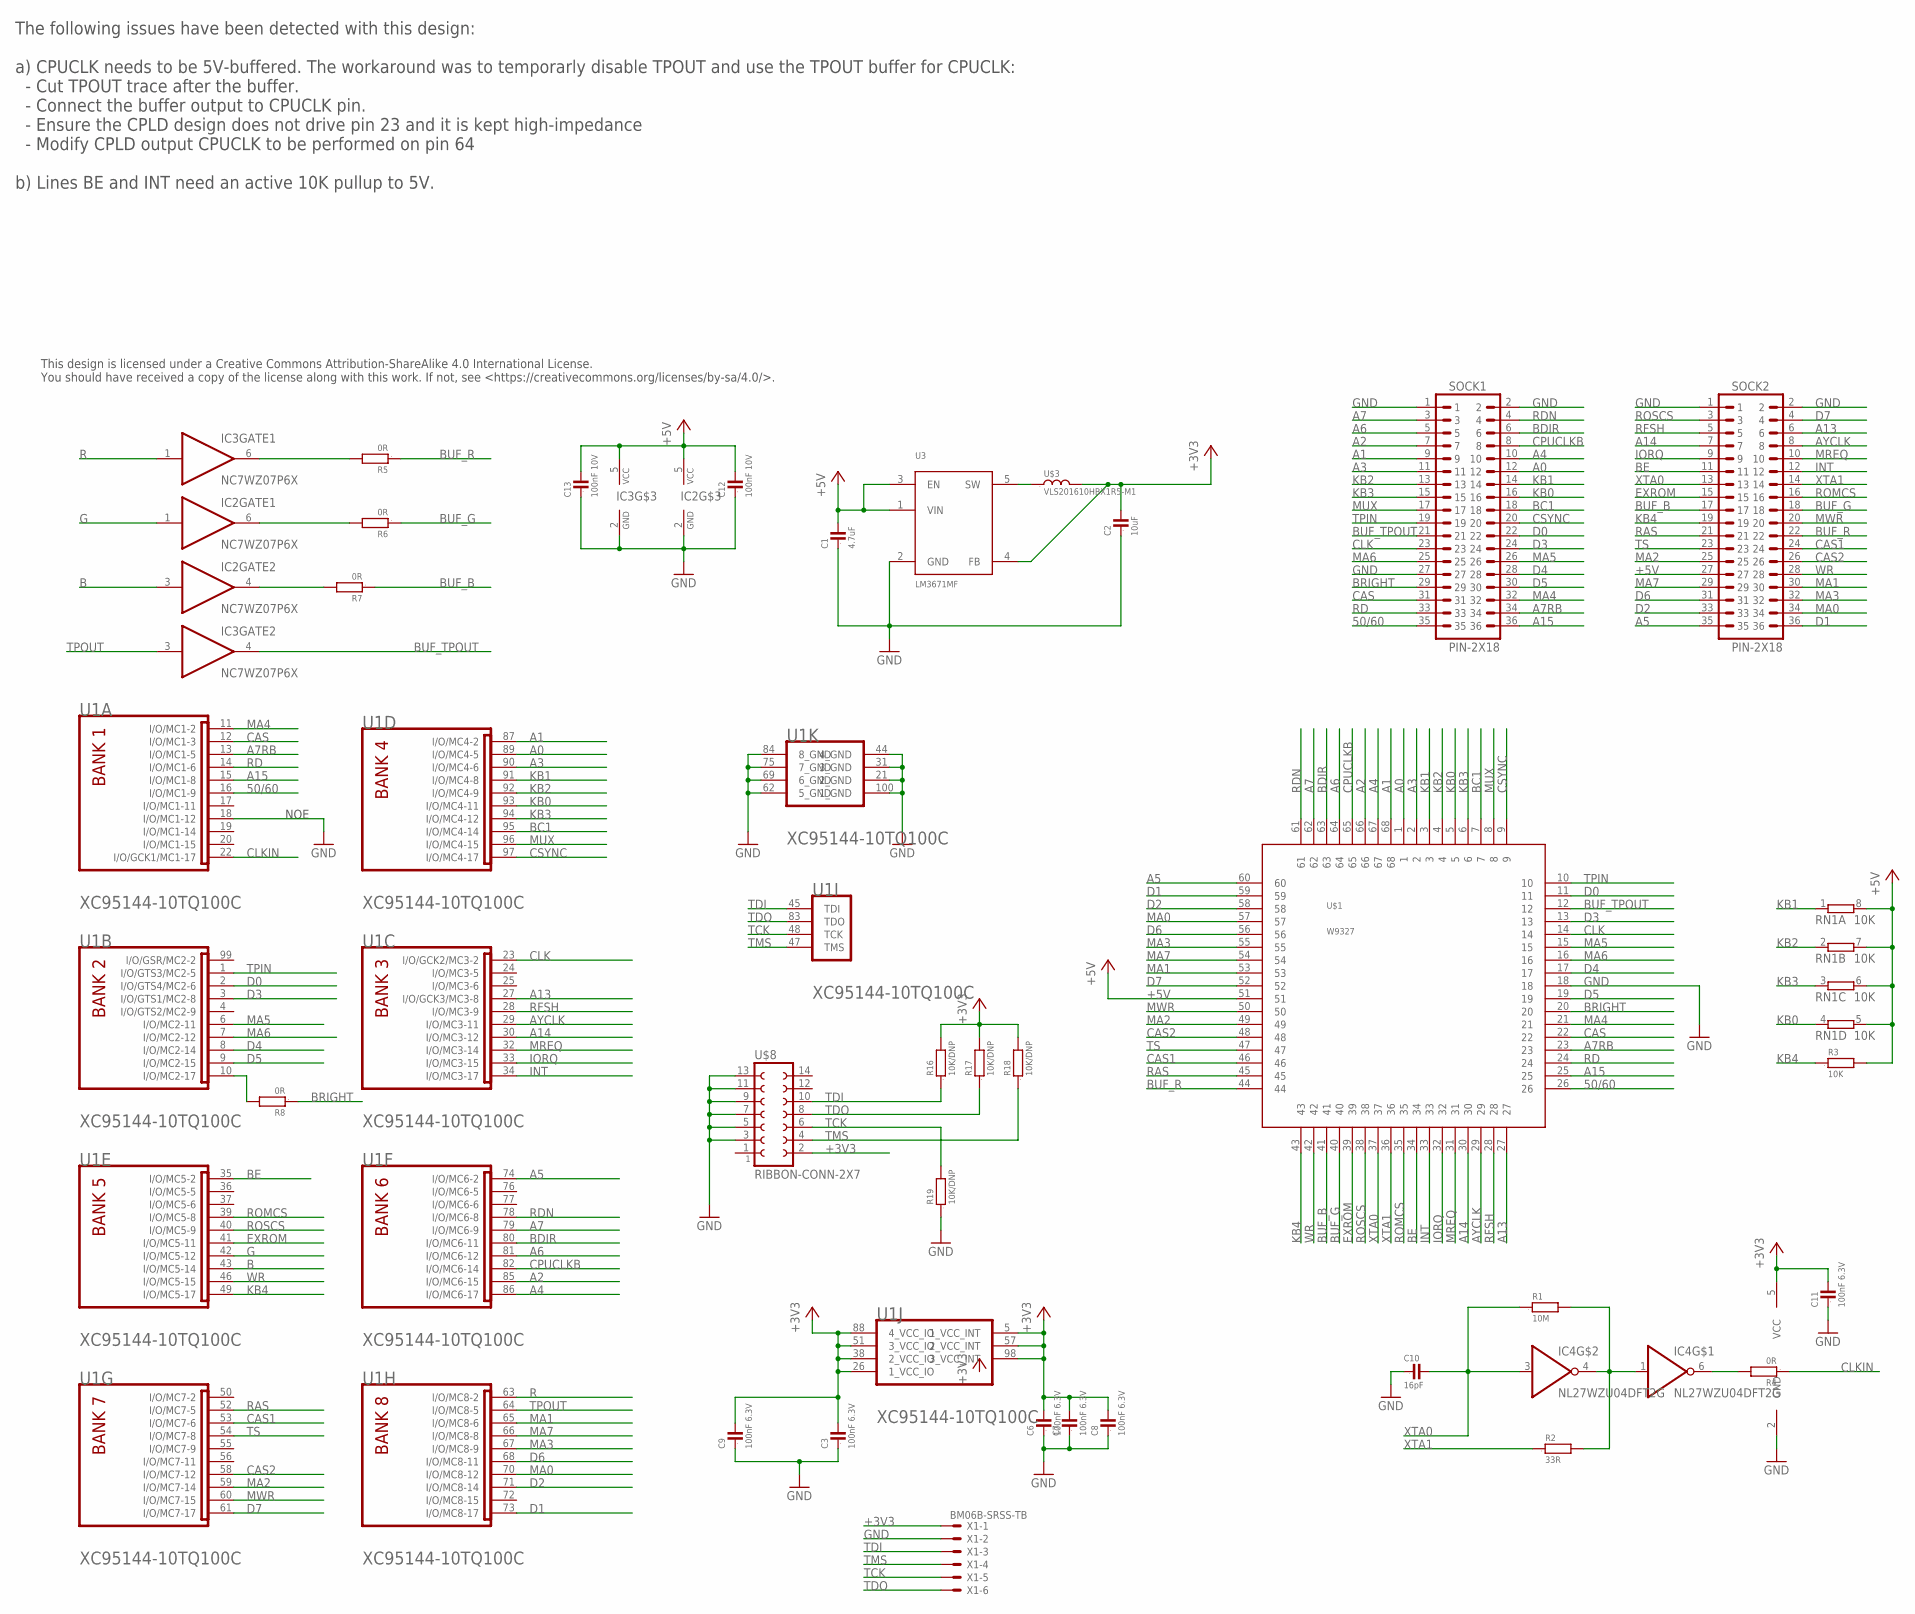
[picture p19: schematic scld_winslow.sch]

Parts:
C1: 4.7uF; 0805
C2: 10uF; 0805
C3, C6, C7, C8, C9, C11: 100nF 6.3V; 0402
C10: 16pF; 0402
C12, C13: 100nF 10V; 0402
IC2, IC3: NC7WZ07P6X; SC70-6
IC4: NL27WZU04DFT2G; SC70-6
R1: 10M; 0402
R2: 33R; 0402
R3: 10K; 0402
R4, R5, R6, R7, R8: 0R; 0603
R16, R17, R18, R19: 10K/DNP; 0603
RN1: 10K; EXB28V
SOCK1, SOCK2: PIN-2X18
U1: XILINX_XC95144-10TQ100CLQFP; LQFP100
U3: LM3671MF; SOT23-5L
U$1: W9327
U$3: VLS201610HBX1R5-M1; IND_0806
U$8: RIBBON-CONN-2X7
X1: BM06B-SRSS-TB

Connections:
50/60: SOCK1.35, U1.16 (I/O/MC1-9), U$1.26
+3V3: C2.2, C3.2, C6.2, C7.2, C8.2, C9.2, C11.2, IC4.5 (VCC), R16.2, R17.2, R18.2, U1.5 (1_VCC_INT), U1.26 (1_VCC_IO), U1.38 (2_VCC_IO), U1.51 (3_VCC_IO), U1.57 (2_VCC_INT), U1.88 (4_VCC_IO), U1.98 (3_VCC_INT), U3.4 (FB), U$3.P$2 (2), U$8.2, X1.1
+5V: C1.2, C12.2, C13.2, IC2.5 (VCC), IC3.5 (VCC), R3.2, RN1.5 (2), RN1.6 (2), RN1.7 (2), RN1.8 (2), SOCK2.27, U3.1 (VIN), U3.3 (EN), U$1.51
A0: SOCK1.12, U1.89 (I/O/MC4-5), U$1.1
A1: SOCK1.9, U1.87 (I/O/MC4-2), U$1.68
A2: SOCK1.7, U1.85 (I/O/MC6-15), U$1.66
A3: SOCK1.11, U1.90 (I/O/MC4-6), U$1.2
A4: SOCK1.10, U1.86 (I/O/MC6-17), U$1.67
A5: SOCK2.35, U1.74 (I/O/MC6-2), U$1.60
A6: SOCK1.5, U1.81 (I/O/MC6-12), U$1.64
A7: SOCK1.3, U1.79 (I/O/MC6-9), U$1.62
A7RB: SOCK1.34, U1.13 (I/O/MC1-5), U$1.23
A13: SOCK2.6, U1.27 (I/O/GCK3/MC3-8), U$1.27
A14: SOCK2.7, U1.30 (I/O/MC3-12), U$1.30
A15: SOCK1.36, U1.15 (I/O/MC1-8), U$1.25
AYCLK: SOCK2.8, U1.29 (I/O/MC3-11), U$1.29
B: IC2.3 (I), U1.43 (I/O/MC5-14)
BC1: SOCK1.18, U1.95 (I/O/MC4-14), U$1.7
BDIR: SOCK1.6, U1.80 (I/O/MC6-11), U$1.63
BE: SOCK2.11, U1.35 (I/O/MC5-2), U$1.34
BRIGHT: R8.1, SOCK1.29, U$1.20
BUF_B: R7.1, SOCK2.17, U$1.41
BUF_G: R6.1, SOCK2.18, U$1.40
BUF_R: R5.1, SOCK2.22, U$1.44
BUF_TPOUT: IC3.4 (O), SOCK1.21, U$1.12
CAS: SOCK1.31, U1.12 (I/O/MC1-3), U$1.22
CAS1: SOCK2.24, U1.53 (I/O/MC7-6), U$1.46
CAS2: SOCK2.26, U1.58 (I/O/MC7-12), U$1.48
CLK: SOCK1.23, U1.23 (I/O/GCK2/MC3-2), U$1.14
CLKIN: R4.1, U1.22 (I/O/GCK1/MC1-17)
CPUCLKB: SOCK1.8, U1.82 (I/O/MC6-14), U$1.65
CSYNC: SOCK1.20, U1.97 (I/O/MC4-17), U$1.9
D0: SOCK1.22, U1.2 (I/O/GTS4/MC2-6), U$1.11
D1: SOCK2.36, U1.73 (I/O/MC8-17), U$1.59
D2: SOCK2.33, U1.71 (I/O/MC8-14), U$1.58
D3: SOCK1.24, U1.3 (I/O/GTS1/MC2-8), U$1.13
D4: SOCK1.28, U1.8 (I/O/MC2-14), U$1.17
D5: SOCK1.30, U1.9 (I/O/MC2-15), U$1.19
D6: SOCK2.31, U1.68 (I/O/MC8-11), U$1.56
D7: SOCK2.4, U1.61 (I/O/MC7-17), U$1.52
EXROM: SOCK2.15, U1.41 (I/O/MC5-11), U$1.39
G: IC2.1 (I), U1.42 (I/O/MC5-12)
GND: C1.1, C2.1, C3.1, C6.1, C7.1, C8.1, C9.1, C10.1, C11.1, C12.1, C13.1, IC2.2 (GND), IC3.2 (GND), IC4.2 (GND), R19.1, SOCK1.1, SOCK1.2, SOCK1.27, SOCK2.1, SOCK2.2, U1.18 (I/O/MC1-12), U1.21 (2_GND), U1.31 (3_GND), U1.44 (4_GND), U1.62 (5_GND), U1.69 (6_GND), U1.75 (7_GND), U1.84 (8_GND), U1.100 (1_GND), U3.2 (GND), U$1.18, U$8.3, U$8.5, U$8.7, U$8.9, U$8.11, U$8.13, X1.2
INT: SOCK2.12, U1.34 (I/O/MC3-17), U$1.33
IORQ: SOCK2.9, U1.33 (I/O/MC3-15), U$1.32
KB0: RN1.4 (1), SOCK1.16, U1.93 (I/O/MC4-11), U$1.5
KB1: RN1.1, SOCK1.14, U1.91 (I/O/MC4-8), U$1.3
KB2: RN1.2 (1), SOCK1.13, U1.92 (I/O/MC4-9), U$1.4
KB3: RN1.3 (1), SOCK1.15, U1.94 (I/O/MC4-12), U$1.6
KB4: R3.1, SOCK2.19, U1.49 (I/O/MC5-17), U$1.43
MA0: SOCK2.34, U1.70 (I/O/MC8-12), U$1.57
MA1: SOCK2.30, U1.65 (I/O/MC8-6), U$1.53
MA2: SOCK2.25, U1.59 (I/O/MC7-14), U$1.49
MA3: SOCK2.32, U1.67 (I/O/MC8-9), U$1.55
MA4: SOCK1.32, U1.11 (I/O/MC1-2), U$1.21
MA5: SOCK1.26, U1.6 (I/O/MC2-11), U$1.15
MA6: SOCK1.25, U1.7 (I/O/MC2-12), U$1.16
MA7: SOCK2.29, U1.66 (I/O/MC8-8), U$1.54
MREQ: SOCK2.10, U1.32 (I/O/MC3-14), U$1.31
MUX: SOCK1.17, U1.96 (I/O/MC4-15), U$1.8
MWR: SOCK2.20, U1.60 (I/O/MC7-15), U$1.50
unnamed: IC4.6 (O), R4.2
unnamed: R8.2, U1.10 (I/O/MC2-17)
unnamed: IC3.6 (O), R5.2
unnamed: U3.5 (SW), U$3.P$1 (1)
unnamed: IC4.1 (I), IC4.4 (O), R1.2, R2.2
unnamed: IC2.4 (O), R7.2
unnamed: IC2.6 (O), R6.2
R: IC3.1 (I), U1.63 (I/O/MC8-2)
RAS: SOCK2.21, U1.52 (I/O/MC7-5), U$1.45
RD: SOCK1.33, U1.14 (I/O/MC1-6), U$1.24
RDN: SOCK1.4, U1.78 (I/O/MC6-8), U$1.61
RFSH: SOCK2.5, U1.28 (I/O/MC3-9), U$1.28
ROMCS: SOCK2.16, U1.39 (I/O/MC5-8), U$1.35
ROSCS: SOCK2.3, U1.40 (I/O/MC5-9), U$1.38
TCK: R19.2, U1.48 (TCK), U$8.6, X1.5
TDI: R16.1, U1.45 (TDI), U$8.10, X1.3
TDO: R17.1, U1.83 (TDO), U$8.8, X1.6
TMS: R18.1, U1.47 (TMS), U$8.4, X1.4
TPIN: SOCK1.19, U1.1 (I/O/GTS3/MC2-5), U$1.10
TPOUT: IC3.3 (I), U1.64 (I/O/MC8-5)
TS: SOCK2.23, U1.54 (I/O/MC7-8), U$1.47
WR: SOCK2.28, U1.46 (I/O/MC5-15), U$1.42
XTA0: C10.2, IC4.3 (I), R1.1, SOCK2.13, U$1.37
XTA1: R2.1, SOCK2.14, U$1.36

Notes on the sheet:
NOE
The following issues have been detected with this design: a) CPUCLK needs to be 5V-buffered. The workaround was to temporarly disable TPOUT and use the TPOUT buffer for CPUCLK: - Cut TPOUT trace after the buffer. - Connect the buffer output to CPUCLK pin. - Ensure the CPLD design does not drive pin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
This design is licensed under a Creative Commons Attribution-ShareAlike 4.0 International License. You should have received a copy of the license along with this work. If not, see <https://creativecommons.org/licenses/by-sa/4.0/>.

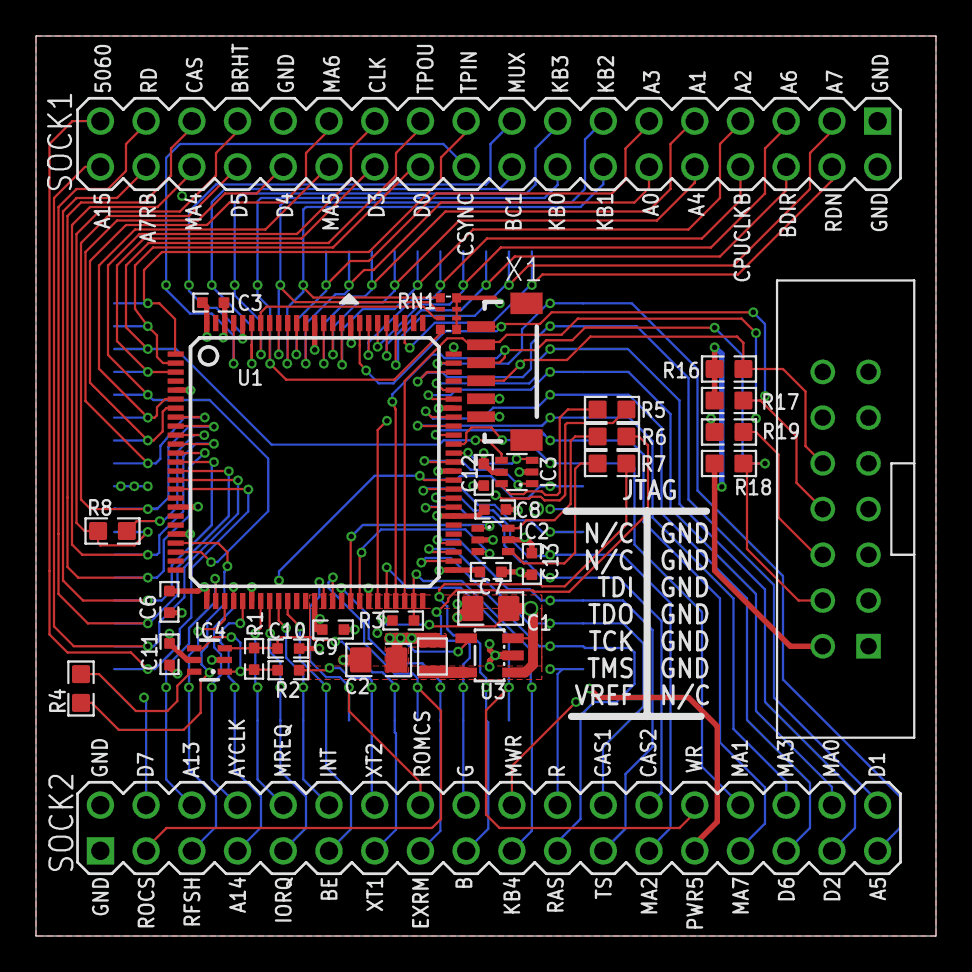
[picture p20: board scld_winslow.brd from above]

Board: 4 copper layers, 50.0 x 50.0 mm, 35 parts (1 on the bottom side), 85 nets.

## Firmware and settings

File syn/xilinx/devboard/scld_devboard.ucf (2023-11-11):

NET	"TPIN" 		LOC="1";
NET	"D<0>" 		LOC="2";
NET	"D<3>" 		LOC="3";
//NET	"CPUCLK"	LOC="4";
NET	"MA<5>"		LOC="6";
NET	"MA<6>"		LOC="7";
NET	"D<4>"		LOC="8";
NET	"D<5>"		LOC="9";
NET	"BRIGHT"	LOC="10";
NET	"MA<4>"		LOC = "11";
NET	"CAS" 		LOC = "12";
NET	"A7RB" 		LOC = "13";
NET	"RD" 		LOC = "14";
NET	"A<15>" 	LOC = "15";
NET	"P5060"		LOC = "16";
//NET	"NOE" 		LOC="18";
NET	"SCLD_CLK"	LOC = "22";
NET	"CPUCLK"	LOC = "23";
NET	"A<13>"		LOC = "27";
NET	"RFSH"		LOC = "28";
NET	"AYCLK"		LOC = "29";
NET	"A<14>"		LOC = "30";
NET	"MREQ"		LOC = "32";
NET	"IORQ"		LOC = "33";
NET	"INT"		LOC = "34";

NET	"BE"		LOC = "35";
NET	"ROMCS"		LOC = "39";
NET	"ROSCS"		LOC = "40";
NET	"EXROM"		LOC = "41";
NET	"G"		LOC = "42";
NET	"B"		LOC = "43";
NET	"WR"		LOC = "46";
NET	"KB<4>"		LOC = "49";

NET	"RAS"		LOC = "52";
NET	"CAS1"		LOC = "53";
NET	"TS"		LOC = "54";
NET	"CAS2"		LOC = "58";
NET	"MA<2>"		LOC = "59";
NET	"MWE"		LOC = "60";
NET	"D<7>"		LOC = "61";

NET	"R"		LOC = "63";
NET	"TPOUT"		LOC = "64";
NET	"MA<1>"		LOC = "65";
NET	"MA<7>"		LOC = "66";
NET	"MA<3>"		LOC = "67";
NET	"D<6>"		LOC = "68";
NET	"MA<0>"		LOC = "70";
NET	"D<2>"		LOC = "71";
NET	"D<1>"		LOC = "73";

NET	"A<5>"		LOC = "74";
NET	"RDN"		LOC = "78";
NET	"A<7>"		LOC = "79";
NET	"BDIR"		LOC = "80";
NET	"A<6>"		LOC = "81";
NET	"CPUCLKB"	LOC = "82";
NET	"A<2>"		LOC = "85";
NET	"A<4>"		LOC = "86";

NET	"A<1>"		LOC = "87";
NET	"A<0>"		LOC = "89";
NET	"A<3>"		LOC = "90";
NET	"KB<1>"		LOC = "91";
NET	"KB<2>"		LOC = "92";
NET	"KB<0>"		LOC = "93";
NET	"KB<3>"		LOC = "94";
NET	"BC1"		LOC = "95";
NET	"MUX"		LOC = "96";
NET	"CSYNC"		LOC = "97";

NET 	"SCLD_CLK" 	TNM_NET = SCLD_CLK;
TIMESPEC TS_SCLD_CLK = PERIOD "SCLD_CLK" 14 MHz HIGH 50%;

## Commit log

2023-11-11 Intial import of TIMEX SCLD CPLD implementation, reverse engineering board and development board.
    [reveng-cpuonly-smdsock.brd, reveng-cpuonly-smdsock.sch, scld_winslow.brd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]
2026-10-09 Make the TC2068 boot: read back ports FFh/F4h, qualify ROM selects with /MREQ
    The SCLD model did not boot a TC2068. It came up in the wrong video mode
    with interrupts disabled. Two things were missing, and each is needed.
    1. Ports FFh and F4h were write-only. Only FEh answered a read.
    The TC2068 ROMs never write either port blind. Every bank switch is a
    read-modify-write. The first one is in the HOME ROM at 0E0Bh, on the way
    to copying the EXROM service code to 6200h:
    LD A,01h
    OUT (F4h),A
    IN A,(FFh)
    SET 7,A
    OUT (FFh),A
    The EXROM does the same at nine places for F4h and ten for FFh. With no
    answer the Z80 read a floating bus, set on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
2026-10-09 sim: boot a TC2068 around the SCLD and capture the screen
    A testbench that wires the SCLD into a minimal TC2068 -- T80a, 4416 video
    and upper RAM, 74LS245, the real HOME ROM and EXROM -- runs it from reset
    and writes the last frame of video as a PNG. It also logs every access to
    ports FFh and F4h, flags a read that does not return what was written, and
    flags two outputs driving the bus when the Z80 latches it.
    The T80 core, the memory and buffer models and the ROMs are not in this
    repository; run.sh takes their locations. The board wiring around the SCLD
    is a reconstruction, not taken from a TC2068 netlist; the testbench header
    says where.
2026-10-09 sim: run at 50 Hz by default, and capture exactly one frame
    The bench strapped P5060 low, which is the 60 Hz, 262-line setting, while
    the converter assumed 312 lines; the picture was one frame followed by the
    top of the next. The strap is now a generic (HZ50, default true; HZ=60 in
    run.sh for the other) and the converter measures the frame from one
    vertical sync to the next.
    The boot result is the same at both rates.
2026-10-11 Hold the CPU, and raise TS, on the 192 display lines only
    The contention block gated the CPU stall on the horizontal counter alone,
    and TS was generated the same way, so the SCLD took the video RAM and held
    the CPU off it on every scanline of the frame, border and blanking lines
    included. RAS and CAS were already gated by vdisplay_s, so on those lines
    nothing was being fetched.
    Both now take vdisplay_s. With 4000h on the address bus the CPU clock ran
    128 periods on a border line; it now runs the full 224, and TS goes from
    4992 pulses a frame to 3072 (192 lines x 16).
    This agrees with what is known of the real chip:
    - TS2068 Technical Manual, 2.1.8.2: the CPU clock "runs continuously excep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
2026-10-11 sim: check that only the display lines are contended
    tb_display_lines runs the SCLD alone for one frame with 4000h parked on the
    address bus and counts, per scanline, the TS pulses and the CPU clock
    periods. It fails unless the first 192 lines show 16 TS pulses and a
    stretched clock, and every other line shows none and the full 224 periods.
    run_display_lines.sh needs only txt_util.vhd from MODELS and takes a few
    seconds. It passes at 50 and 60 Hz, and fails on the RTL before the previous
    commit with 120 of 312 lines wrong.
2026-10-11 Give a Z80 refresh cycle a whole RAS pulse or none
    The SCLD passes Z80 refresh cycles to the video RAM only outside its fetch
    window, and refresh_ras_s took that permission straight from hcounter_s(9).
    A refresh cycle under way when the counter crossed 511->512 or 895->0
    therefore had its RAS started or ended at the crossing instead of with the
    cycle.
    The refresh RAS is short here (half a clock period, 140 ns), so this is
    rare, and in zero-delay simulation the case at 512 is a race: the counter
    bit rises in the same instant as /MREQ, and the pulse has zero width. On
    hardware /MREQ rises a little after the clock edge, so the pulse could be
    as long as that delay, which is less than the DRAM's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

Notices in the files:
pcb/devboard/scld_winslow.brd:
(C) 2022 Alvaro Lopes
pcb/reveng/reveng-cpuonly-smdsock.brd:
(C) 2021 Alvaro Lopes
